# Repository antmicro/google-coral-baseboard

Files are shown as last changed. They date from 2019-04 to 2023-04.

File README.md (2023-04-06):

# Antmicro's Google Coral Baseboard

Copyright (c) 2019-2023 [Antmicro](https://www.antmicro.com)



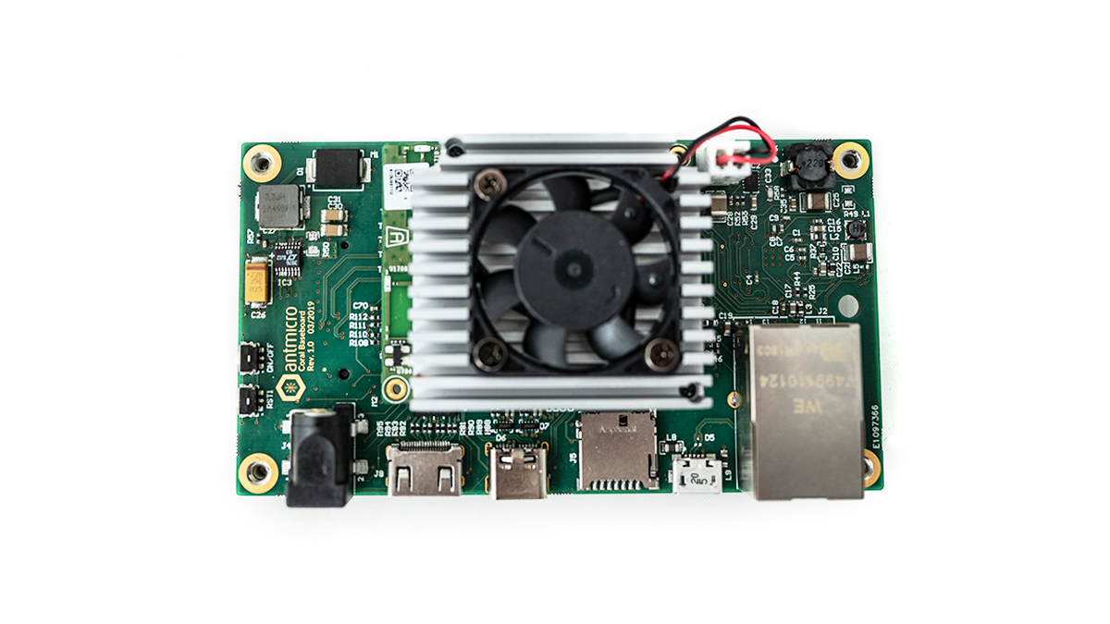
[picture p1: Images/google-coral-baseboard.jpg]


## Overview

This project contains open hardware design files for a baseboard supporting the [Google Coral SoM](https://coral.withgoogle.com/products/som) with NXP i.MX8X and Google's Edge TPU ML inference ASIC (also available as part of the [Coral Edge TPU Development Board](https://coral.withgoogle.com/products/dev-board), created by [Antmicro](https://www.antmicro.com).
The board provides standard I/O interfaces and allows the user to interface with two MIPI CSI-2 compatible video devices over a unified Flexible Flat Cable (FFC) connector.

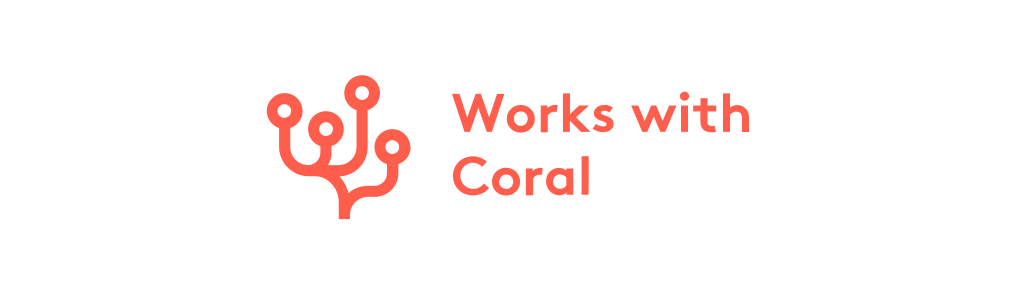
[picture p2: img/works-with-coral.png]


## Key features

* Interface connectors for the Coral Edge TPU module
* Gigabit Ethernet RJ45 connector
* Micro USB serial debug connector
* Micro SD card interface
* 50-pin FFC connectors exposing MIPI CSI-2 camera interfaces
* USB-C DFP (Host) port
* Mini HDMI video output interface
* Integrated DC/DC power supply accepting 6-36VDC of input voltage

The PCB project files were prepared in Altium Designer 14.1.

## Project structure

The main directory contains Altium project file, documentation script a
LICENSE and README. The remaining files are stored in the following
directories:

*   `Libraries` - contains the component libraries
*   `img` - contains graphics for this README
*   `PCB` - contains schematics and layout files 
*   `Documentation` - contains PDF schematic and generated assembly assets

## Getting started

The board can be produced and assembled using the provided design files.
Please take a look at the mechanical layers for more information regarding the PCB stackup recommended for fabrication.
The board accepts power supply voltage in the 6-36VDC range.
It is recommended to use a 12V 2A DC supply to power the board.
The board has an integrated power sequencer that starts the module automatically right after applying the power supply.
Please refer to the Coral documentation for more details regarding the [flashing procedure](https://coral.withgoogle.com/tutorials/devboard-reflash).

### Debug UART connection

Most of the debug messages are provided through the serial console.
The board is equipped with an FTDI chip exposing both UART interfaces to the host PC.
Please refer to the schematic sheets for more details.
The default debug UART channel is accessible through `/dev/ttyUSB0` (assuming that there are no other FTDI units connected to your PC).
The default baudrate for the serial debug connection is 115200 baud with 8-bit transmission, 1 stop bit and with no flow control.

## License

This project is licensed under the [Apache-2.0](LICENSE) license.

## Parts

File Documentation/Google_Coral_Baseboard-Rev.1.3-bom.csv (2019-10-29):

Designator | PartNumber | Value | Description | Manufacturer | MPN | Quantity
C1, C4, C5, C6, C7, C11, C16, C18, C20, C22, C23, C39, C50, C52, C55, C56, C57, C58, C59, C60, C61, C62, C63, C64, C80, C81 | C_100n_0402 | 100n | MLCC SMT Capacitor 100nF 0402 | Walsin | 0402X104K6R3CT | 26
C2, C3, C38, C45, C84, C85, C86 | C_100n_0402 | 100n | MLCC SMT Capacitor 100nF 0402 | Walsin | 0402X104K6R3CT | 7
C8, C9 | C_27p_0402 | 27p | MLCC SMT Capacitor 27pF 0402 | WALSIN | 0402N270J500CT | 2
C10, C25 | C_22u_1210 | 22u | MLCC SMT Capacitor 22uF 1210 | TDK | C3225X5R1A226M230AA | 2
C12 | C_10n_0603 | 10n | MLCC SMT Capacitor 10nF 0603 | AVX | 06031C103JAT2A | 1
C13 | C_100p_0603 | 100p | MLCC SMT Capacitor 100pF 0603 | WALSIN | 0603N101J500CT | 1
C14 | C_10p_0402 | 10p | MLCC SMT Capacitor 10pF 0402 | MULTICOMP | MC0402N100D500CT | 1
C15, C17, C19, C21 | C_4u7_0603 | 4u7 | MLCC SMT Capacitor 4u7F 0603 | TDK | C1608X5R1C475K080AC | 4
C24 | C_2u2_1210 | 2u2 | MLCC SMT Capacitor 2u2F 1210 | TDK | C3225X7R2A225K230AB | 1
C26 | C_100n_0603 | 100n | MLCC SMT Capacitor 100nF 0603 | AVX |  | 1
C27 | C_10n_0402 | 10n | MLCC SMT Capacitor 10nF 0402 | AVX |  | 1
C28 | C_1u_0402 | 1u | MLCC SMT Capacitor 1uF 0402 | Yaego | CC0402KRX5R5BB105 | 1
C29 | C_3n3_0603 | 3n3 | MLCC SMT Capacitor 3n3F 0603 | WALSIN | 0603B332J500CT | 1
C30, C31, C32 | C_2u2_1206 | 2u2 | MLCC SMT Capacitor 2u2F 1206 | Kemet |  | 3
C33 | C_470p_0603 | 470p | MLCC SMT Capacitor 470pF 0603 | AVX | 06031C471JAT2A | 1
C34 | C_4n7_0402 | 4n7 | MLCC SMT Capacitor 4n7F 0402 | TDK |  | 1
C35 | C_2n2_0603 | 2n2 | MLCC SMT Capacitor 2n2F 0603 | AVX | 06035C222KAT2A | 1
C36 | C_47p_0402 | 47p | MLCC SMT Capacitor 47pF 0402 | KEMET |  | 1
C37, C41 | C_1u_0603 | 1u | MLCC SMT Capacitor 1uF 0603 | Walsin | 0603F105Z160CT | 2
C40 | C_100u_1210_X5R | 100u | MLCC SMT Capacitor 100uF 1210 X5R | SAMSUNG | CL32A107MQVNNNE | 1
C42 | C_10u_0603 | 10u | MLCC SMT Capacitor 10uF 0603 | AVX | 06036D106MAT2A | 1
C43 | C_100n_0603 | 100n | MLCC SMT Capacitor 100nF 0603 | AVX |  | 1
C44 | C_47u_0805 | 47u | MLCC SMT Capacitor 47uF 0805 | KEMET |  | 1
C65, C66 | C_4u7_0402 | 4u7 | MLCC SMT Capacitor 4u7F 0402 | MURATA | GRM155R60G475ME | 2
C67, C68 | C_1u_0402 | 1u | MLCC SMT Capacitor 1uF 0402 | Yaego | CC0402KRX5R5BB105 | 2
C75, C76, C77 | C_47u_0805 | 47u | MLCC SMT Capacitor 47uF 0805 | KEMET |  | 3
C78, C79 | C_27p_0402 | 27p | MLCC SMT Capacitor 27pF 0402 | WALSIN | 0402N270J500CT | 2
C82, C83 | C_2p_0402 | 2p | MLCC SMT Capacitor 2p 0402 | TDK | C1005C0G1H020B050BA | 2
D1 | PDS760-13 | PDS760-13 | Schottky Diodes & Rectifiers SCHOTTKY RECTIFIER | DIODES INC. | PDS760-13 | 1
D2, D8, D9 | TPD2E009DRTR | TPD2E009DRTR | ESD Suppressors 2-CH | Texas Instruments | TPD2E009DRTR | 3
D4 | TPD6E05U06_PASS | TPD6E05U06 | ESD Suppressors 6-CH Pass through layout | Texas Instruments | TPD6E05U06RVZR | 1
D5 | TPD2E009DRTR | TPD2E009DRTR | ESD Suppressors 2-CH | Texas Instruments | TPD2E009DRTR | 1
D6, D7 | TPD4E05U06_PASS | TPD4E05U06 | ESD Suppressors 4-CH | Texas Instruments | TPD4E05U06DQAR | 2
D10 | 1N4148WS | 1N4148WS | Diode small signal | ON SEMICONDUCTOR | 1N4148WS | 1
F1 | LITTELFUSE_1206L450SLWR | 1206L450SLWR | PTC RESET 6V LO RHO 1206 4.50A | LITTELFUSE | 1206L450SLWR | 1
FAN1 | 022232021 A-6373-02A222 | MX-22-23-2021 | Pinhead connector with key | Molex |  | 1
FAN2 | B2B-PH-K-S(LF)(SN) | B2B-PH-K-S(LF)(SN) |  | JST |  | 1
IC1 | RTL8211F | RTL8211F | Highly Integrated 10/100/1000m Ethernet Transceiver | Realtek |  | 1
IC2 | MAX17502GATB+ | MAX17502GATB+ | DC-DC Switching (Step Down) Regulator, Adjustable, 600 kHz, 4.5V-60Vin, 0.9V-55.2V/1 A out, TDFN-10 | MAXIM INTEGRATED PRODUCTS | MAX17502GATB+ | 1
IC3 | TPS54561-Q1 | TPS54561-Q1 | IC REG BCK SPLIT RAIL ADJ 10WSON | TEXAS INSTRUMENTS | TPS54561-Q1 | 1
IC4 | FT2232D | FT2232D | Dual USB-UART/FIFO | FTDI | FT2232D-REEL | 1
IC5 | NCP380HSNAJAAT1G | NCP380HSNAJAAT1G | POWER LOAD SWITCH, HIGH SIDE | ON Semiconductor |  | 1
IC6 | HD3SS3220 | HD3SS3220 | IC DRP PORT CTLR USB-C 30WQFN | Texas Instruments |  | 1
IC7 | TPD8S009 | TPD8S009 | 8-Channel ESD Protection for DisplayPort and HDMI | TEXAS INSTRUMENTS |  | 1
IC8 | TLV70018DCKT | TLV70018DCKT | Voltage Regulator, 2V to 5.5V, 175mV Dropout, 1.8Vout, 200mAout | TEXAS INSTRUMENTS | TLV70018DCKT | 1
IC9 | PTN5150 | PTN5150 | CC logic for USB Type-C applications | NXP |  | 1
J1 | WE-687-150-145-22 | 68715014522 | 0.50mm SMT ZIF Horizontal Bottom Contact WR-FPC | WURTH ELEKTRONIK | 68715014522 | 1
J2 | WE_7499110124 | WE_7499110124 | LAN-Transformer WE-RJ45LAN 10/100/1000 BaseT | Wurth Elektronik | WE_7499110124 | 1
J4 | WE-694106106102 | 694106106102 | DC Power Jack Right Angled SMT Ø6.4 with 4 soldering pads & pegs WR-DC | WURTH ELEKTRONIK | 694106106102 | 1
J5 | AMP-114-00841-68 | 114-00841-68 | Micro SD card holder | AMPHENOL COMMERCIAL PRODUCTS | 114-00841-68 | 1
J6 | CON-Molex-47346-0001 | Molex 47346-0001 | USB - micro B Receptacle Connector 5 Position Surface Mount, Right Angle, Horizontal | Molex | 473460001 | 1
J7 | CON-Molex-105450-0101 | 105450-0101 | USB-C connector | Molex |  | 1
J8 | WE_685119136923 | 685119136923 | CONN HDMI FEMALE R/A 19POS 2.6MM | WURTH ELEKTRONIK |  | 1
J9 | CON-Molex-47346-0001 | Molex 47346-0001 | USB - micro B Receptacle Connector 5 Position Surface Mount, Right Angle, Horizontal | Molex | 473460001 | 1
JM0, JM1, JM3 | DF40HC(3.0)-100DS-0.4V(51) | DF40HC(3.0)-100DS-0.4V(51) | CONN RCPT 100POS 0.4MM SMD GOLD | Hirose |  | 3
L1 | ELLVGG4R7N | ELLVGG4R7N | PANASONIC ELECTRONIC COMPONENTS ELLVGG4R7N Surface Mount Power Inductor, Choke Coil, ELL-VGG Series, 4.7 ?H, ? 30%, Shielded, 0.17 ohm, 980 mA | PANASONIC ELECTRONIC COMPONENTS ELLVGG4R7N PANASONIC ELECTRONIC COMPONENTS | ELLVGG4R7N | 1
L2, L3, L4, L5 | BLM18PG330SN1D | BLM18PG330SN1D | MURATA BLM18PG330SN1D FERRITE BEAD, 0.025OHM, 3A, 0603 | MURATA | BLM18PG330SN1D | 4
L6 | 744777122 | 744777122 | Surface Mount Power Inductor, WE-PD Series, 22 µH, 1.41 A, 1.7 A, Shielded, 0.11 ohm | WURTH ELEKTRONIK | 744777122 | 1
L7 | WE_7447798720 | WE_7447798720 | Fixed Inductors WE-PDF 1064 7.2uH 7.9A 12.8mOhm | WURTH ELEKTRONIK |  | 1
L8 | 742792022 | 742792022 | WURTH ELEKTRONIK - 742792022 - FERRITE BEAD, 0.05OHM, 2A, 0805 | WURTH ELEKTRONIK | 742792022 | 1
L9 | BLM18SG121TN1D | BLM18SG121TN1D | FERRITE BEAD, 0.025OHM, 3A, 0603 | MURATA | BLM18SG121TN1D | 1
L10 | BLM18EG221SN1D | BLM18EG221SN1D | MURATA BLM18EG221SN1D FERRITE BEAD, 0.05OHM, 2A, 0603 | MURATA | BLM18EG221SN1D | 1
L11 | 742792022 | 742792022 | WURTH ELEKTRONIK - 742792022 - FERRITE BEAD, 0.05OHM, 2A, 0805 | WURTH ELEKTRONIK | 742792022 | 1
L12 | BLM18SG121TN1D | BLM18SG121TN1D | FERRITE BEAD, 0.025OHM, 3A, 0603 | MURATA | BLM18SG121TN1D | 1
L13 | BLM18AG601SN1D | BLM18AG601SN1D | Ferrite Bead, 600 ohm, 0603 [1608 Metric], BLM18A Series, 500 mA, 0.38 ohm, ? 25% | MURATA | BLM18AG601SN1D | 1
LED1 | LED_R | KPT-1608EC | LED Red 0603 case | KINGBRIGHT | KPT-1608EC | 1
M2 | Edge-TPU-SOM-model |  | Edge TPU SOM |  |  | 1
ON/OFF, RST1 | TL3340AF160QG | TL3340AF160QG | E-SWITCH TL3340AF160QG SWITCH, TACTILE SPST 50mA, SMD GULL WING | E-SWITCH |  | 2
Q1 | NX5427001Z | NX5427001Z | CLOCK SAW OSCILLATOR SEAM5032 | Diodes Incorporated |  | 1
Q2 | PMV32UP | PMV32UP | P CH, 20V, 4A | NXP | PMV32UP | 1
R1, R2, R3, R4 | R_2k_0402 | 2k | SMT Resistor 2k 0402 | VISHAY | CRCW04022K00FKED | 4
R6, R7, R8, R9, R10, R19, R20, R22, R23, R82, R86 | R_4k7_0402 | 4k7 | SMT Resistor 4k7 0402 | PANASONIC ELECTRONIC COMPONENTS | ERJ2GEJ472X | 11
R16, R60, R61, R62, R63, R64, R65, R66, R87, R101, R116, R121, R122, R123, R126 | R_10k_0402 | 10k | SMT Resistor 0402 | VISHAY | CRCW040210K0FKEDHP | 15
R26, R44, R98, R132, R133, R134, R135, R136, R137, R138 | R_0R_0402 | 0R | SMT Resistor 0402 |  |  | 10
R27, R28, R29, R30, R32, R33, R39, R41, R43, R47, R71, R76, R77, R83, R84, R96, R97, R120, R127, R128, R129, R130 | R_0R_0402 | 0R | SMT Resistor 0402 |  |  | 22
R31 | R_220R_0402 | 220R | SMT Resistor 220R 0402 | TE CONNECTIVITY / NEOHM | CRG0402J220R | 1
R34, R35, R36, R38, R40, R42 | R_22R_0402 | 22R | SMT Resistor 22R 0402 | VISHAY | CRCW040222R0FKED | 6
R37 | R_2k49_0603_1% | 2k49 | SMT Resistor 2k49 0603 1% | Vishay | CRCW06032K49FKEA | 1
R45 | R_2k_0402 | 2k | SMT Resistor 2k 0402 | VISHAY | CRCW04022K00FKED | 1
R46, R58 | R_10k_0402 | 10k | SMT Resistor 0402 | VISHAY | CRCW040210K0FKEDHP | 2
R48, R49, R67 | R_0R_0805 | 0R | SMT Resistor 0R 0805 | VISHAY | CRCW08050000Z0EA | 3
R50, R53, R79, R80 | R_2k2_0402 | 2k2 | RES, 2k2, 0402, 5% | MULTICOMP | MCWR04X2201FTL | 4
R51 | R_3M3_0402 | 3M3 | SMT Resistor 3M3 0402 | WELWYN | ASC0402-3M3FT10 | 1
R52 | R_44k2_0402 | 44k2 | SMT Resistor 0402 | PANASONIC ELECTRONIC COMPONENTS | ERJ2RKF4422X | 1
R55 | R_16k5_0402_0.1% | 16k5 | RES, 16k5, 0402, 0.1% | PANASONIC ELECTRONIC COMPONENTS | ERA2AEB1652X | 1
R56 | R_0R_1206 | 0R | RES, 0R, 1206 |  |  | 1
R57 | R_243k_0402 | 243k | RES, 243k, 0402 |  |  | 1
R59 | R_49R9_0402 | 49R9 | RES, 49R9, 0402 |  |  | 1
R68 | R_470R_0402 | 470R | SMT Resistor 470R 0402 | VISHAY | CRCW0402470RFKED. | 1
R70 | R_470R_0603 | 470R | SMT Resistor 470R 0603 | BOURNS | CR0603-JW-471GLF | 1
R73 | R_5k6_0603 | 5k6 | SMT Resistor 5k6 0603 | PANASONIC ELECTRONIC COMPONENTS | ERJ3GEYJ562V | 1
R74, R78 | R_200k_0402 | 200k | SMT Resistor 200k 0402 | YAGEO (PHYCOMP) | RC0402FR-07200KL | 2
R75 | R_909k_0402 | 909k | SMT Resistor 9k31 0402 | PANASONIC ELECTRONIC COMPONENTS | ERJ2RKF9093X | 1
R88, R89, R90, R91, R92, R93, R94, R95 | R_5R6_0402 | 5R6 | SMD Resistor 0402 | Panasonic | ERJ2GEJ5R6X | 8
R99 | R_0R_0603 | 0R | SMT Resistor 0R 0603 | BOURNS | CR0603-J/-000ELF | 1
R100 | R_1k54_0402 | 1k54 | SMT Resistor 1k54 0402 | VISHAY | CRCW04021K54FKED. | 1
R102 | R_53k6_0402 | 53k6 | SMT Resistor 0402 | TE CONNECTIVITY |  | 1
R103, R104, R105, R106 | R_33R_0402 | 33R | RES, 33R, 0402, 1% | TE CONECTIVITY | CRG0402F33R | 4
R113 | R_16k9_0402 | 16k9 | SMT Resistor 0402 | PANASONIC |  | 1
R114 | R_10k2_0402_0.1% | 10k2 | RES, 10k2, 0402, 0.1% | TE CONECTIVITY | CPF0402B10K2E1 | 1
R115 | R_1M_0402 | 1M | SMT Resistor 1M 0402 | VISHAY | CRCW04021M00FKED | 1
R117, R131 | R_100k_0402 | 100k | SMT Resistor 100k 0402 | VISHAY | CRCW0402100KFKEDHP | 2
R118, R119 | R_1k8_0603 | 1k8 | SMT Resistor 1k8 0603 | VISHAY | CRCW06031K80FKEA | 2
R124, R125 | R_5k11_0402 | 5k11 | SMT Resistor 5k11 0402 | WALSIN | WR04X5111FTL | 2
SW1 |  | TDA02H0SB1 | TDA02H0SB1 - DIP / SIP Switch, 2 Circuits, SPST, SMD, TDA Series, DIP, 24 V | C & K |  | 1
Y1 | CRYSTAL_25MHz_SMD_TXC | 25MHz | CRYSTAL, 25.000MHZ | TXC | 7A-25.000MAAJ-T | 1
Y2 | CRYSTAL_6_MHz_SMD | MQ-6.000-12-30/30/ | CRYSTAL, 6MHZ, 12PF, SMD,30ppm | MERCURY UNITED ELECTRONICS | MQ-6.000-12-30/30/-40+85 | 1

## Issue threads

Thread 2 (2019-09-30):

This board will never power up the SOM

ajawamnet, 2019-09-30:
According to Schmoogle - you need to have pins 93 thru 100 on what you call JM3 (google SOM Dev board J1312) connected to 5 volt.

But your board shows those pins connected to VSYS_5V via polyfuse F1 - and VSYS_5V goes nowhere - see the altium screenshot attached...

AND you show pin 93 tied to GND - not cool

See the screenshot of the Google SOM datasheet - where it states that you MUST connect those pins.

What kind of man-bun, java-jockey crap is this?

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

pkatarzynski, 2019-10-01:
Hi
Thank you for your contribution.
We have updated power delivery for the SOM.

ajawamnet, 2019-10-01:
OK - I'll look for the updated github files

--
WAM
http://www.ajawamnet.com
http://www.ajawamnet.com/ajawamnet/marketturd.htm
------------

More information on my lab and shop:
http://www.ajawamnet.com
http://www.ajawamnet.com/ajawam3/swarf/swarf.htm
------------------------
"Success is going from failure to failure without a loss of enthusiasm."
~~ Sir Winston Leonard Spencer-Churchill (1874-1965)

"I've failed at so many things so many times I make Abraham Lincoln look like Bill Gates"
~~ Wayne Mitzen (1959-  )

"What makes an expert isn't so much what they know,
It's that they've done similar things so many times wrong
They know what not to do"
~~ Wayne Mitzen (1959-  )

"You just keep pushing. You just keep pushing. I made every mistake that could be made. But I just kept pushing."
~~ Rene Descartes 1596-1650

"I hate the way people just go from ignorance to despair so quickly; it's the lazy man's option"
~~Professor Tim Flannery (1956-  )

"When you do things right, people won't be sure you've done anything at all."
~~ God, in Futurama episode "Godfellas"

"Two things are infinite: the universe and human stupidity;
and I'm not even sure about the universe."
~~ Albert Einstein (1879-1955)

"Some scientists claim that hydrogen, because it is so plentiful, is the basic building block of the universe.
I dispute that. I say there is more stupidity than hydrogen, and that is the basic building block of the universe."
~~ Frank Zappa (1940-1993)

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

Closed 2019-10-01.

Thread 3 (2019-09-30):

You also have a problem with parts flipped on layer in the PCB

ajawamnet, 2019-09-30:
Oh and in the Altium PCB file you have multiple parts that are shown as flipped on layer. In Altium 19 you'd never notice this (since they went f'ing brain dead and removed a lot of stuff we've come to depend on) BUT it is an issue if you're using AD17 or lower... this is bad mojo - ask any seasoned Altium user (me - I've done over 3,500 design with their tool since 1995).

Ya might want to fix this...

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

pkatarzynski, 2019-10-01:
Hi

Thank you for your comment.
The design files were prepared in Altium Designer 14.1
We can see that some of the components on bottom layer have the 'flipped on layer' attribute set in the design however the pin arrangement on those footprints matches the physical arrangement on ICs. We will review the component library and unify this.

ajawamnet, 2019-10-02:
The easiest thing to do is to open in AD19 and save out. This will clear the flipped on layer. You can then  use the Make PCBLib.
- Attached is the PCB with the power issue fix (your upload of 191001)   saved out of AD19.1.7 and re-saved as AD14.2 - along with the PCBLib saved out of AD14.2 with the report generated in AD17 (since PCBList in AD14 did not have a column for Flipped on Layer attribute) that shows all the "Flipped on layer" stoopid has been reset.

[PCB-withpwrfix-ad19_to_ad14.zip](https://github.com/antmicro/google-coral-baseboard/files/3681559/PCB-withpwrfix-ad19_to_ad14.zip)

Also note I moved the "Cool ass" open source logo to clear the DRC from the keepout.

BTW - the guy that runs the Free Software Foundation - the GNU thing - Richard Stallman. He HATES the term "Open Source". If you mention  "Open Source" to him more than a few times he'll stop talking/email chatting with you.

The silly I've seen since I started back in the late 1970's ... all the cool man-bun java jockey maker crap - see my rant here: http://www.ajawamnet.com/ajawamnet/mama_i_wanna_be_a_maker.html

Good lord...

ajawamnet, 2019-10-02:
updated PCB doc in AD14.2 format with adjustment for silly Open Source logo bottom soldermask

[PCB-withpwrfix-ad19_to_ad14.zip](https://github.com/antmicro/google-coral-baseboard/files/3682505/PCB-withpwrfix-ad19_to_ad14.zip)

pkatarzynski, 2019-10-04:
Thank you for your assistance. We have updated the PCB components with proper definitions of flipped-on-layer attribute.

Closed 2019-10-04.

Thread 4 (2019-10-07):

BAD MOLEX USB Footprint

ajawamnet, 2019-10-07:
See the attached JPG... also attached is corrected footprint
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

[correctedmlxUSB.zip](https://github.com/antmicro/google-coral-baseboard/files/3698487/correctedmlxUSB.zip)

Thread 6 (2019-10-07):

Lack of SOM Mounting holes as per Google Datasheet

ajawamnet, 2019-10-07:
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

https://coral.withgoogle.com/docs/dev-board/datasheet/

pkatarzynski, 2019-10-07:
Hi ajawamnet
We have dropped mounting holes on purpose in the first revision because of time constraints. Holes will be there in the next revision probably.

Closed 2019-10-07.

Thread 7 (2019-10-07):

Your baseboard has components and copper in the area that Google mentions should be clear of these elements

ajawamnet, 2019-10-07:
See the attached:
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

pkatarzynski, 2019-10-29:
We have added clearance area in revision 1.3

ajawamnet, 2019-10-29:
I hope that's enough - if you look at the Google ref baseboard, note there's nothing beyond the clearance area - the SOM is mounted at the edge of the PCB.  Even on your 1.3 rev, the WiFi will be radiating into your main power inductor ... not sure how that big honkin' piece of ferrite will affect the pattern and the loading/tuning of that PCB antenna they use. Be interesting to see how that works...

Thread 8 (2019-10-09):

SOM Fan connector is incorrect

ajawamnet, 2019-10-09:
The SOM actually uses a 2mm JST connector for the fan

pkatarzynski, 2019-10-09:
We have some heatsink assemblies with fans terminated with Molex KK-Series. The board was originally designed for such a fan. However it is a good idea to support both Molex and JST. We will add JST connector in next revision.

Closed 2019-10-09.

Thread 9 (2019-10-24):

PCIE CLKREQ goes nowhere

ajawamnet, 2019-10-24:
the label PCIE2_nCLKREQ (I2C4_SDA) on JM1 pin 78 does not match the PCIE1_nCLKREQ  label on  M.2 interface pin 52

pkatarzynski, 2019-10-25:
Hi

Thank you for spotting this.
According to the latest datasheet of the Som (https://coral.withgoogle.com/docs/som/datasheet/#pcie)
both PCIe interfaces are used internally.
This information was not available when we designed the very first version of the baseboard. Hence we are going to drop the M.2 at this point.

Closed 2019-10-25.

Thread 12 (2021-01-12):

SOM not working according to this datasheet.

borguleabhijeet, 2021-01-12:
Hello, I have made a pcb to mount SOM product. I am more interested in GPIO pins so I kept other peripherals floating.
The board just take input +5v and Ground. After all pcb fabrication and assembly the SOM module  only heats up and do not get booted. I changed the boot mode but its not working. Can you please help me to solve the issue?
The schematic is attached to below link. I already browned one SOM module. I afraid to connect another one.

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

Closed 2021-01-14.

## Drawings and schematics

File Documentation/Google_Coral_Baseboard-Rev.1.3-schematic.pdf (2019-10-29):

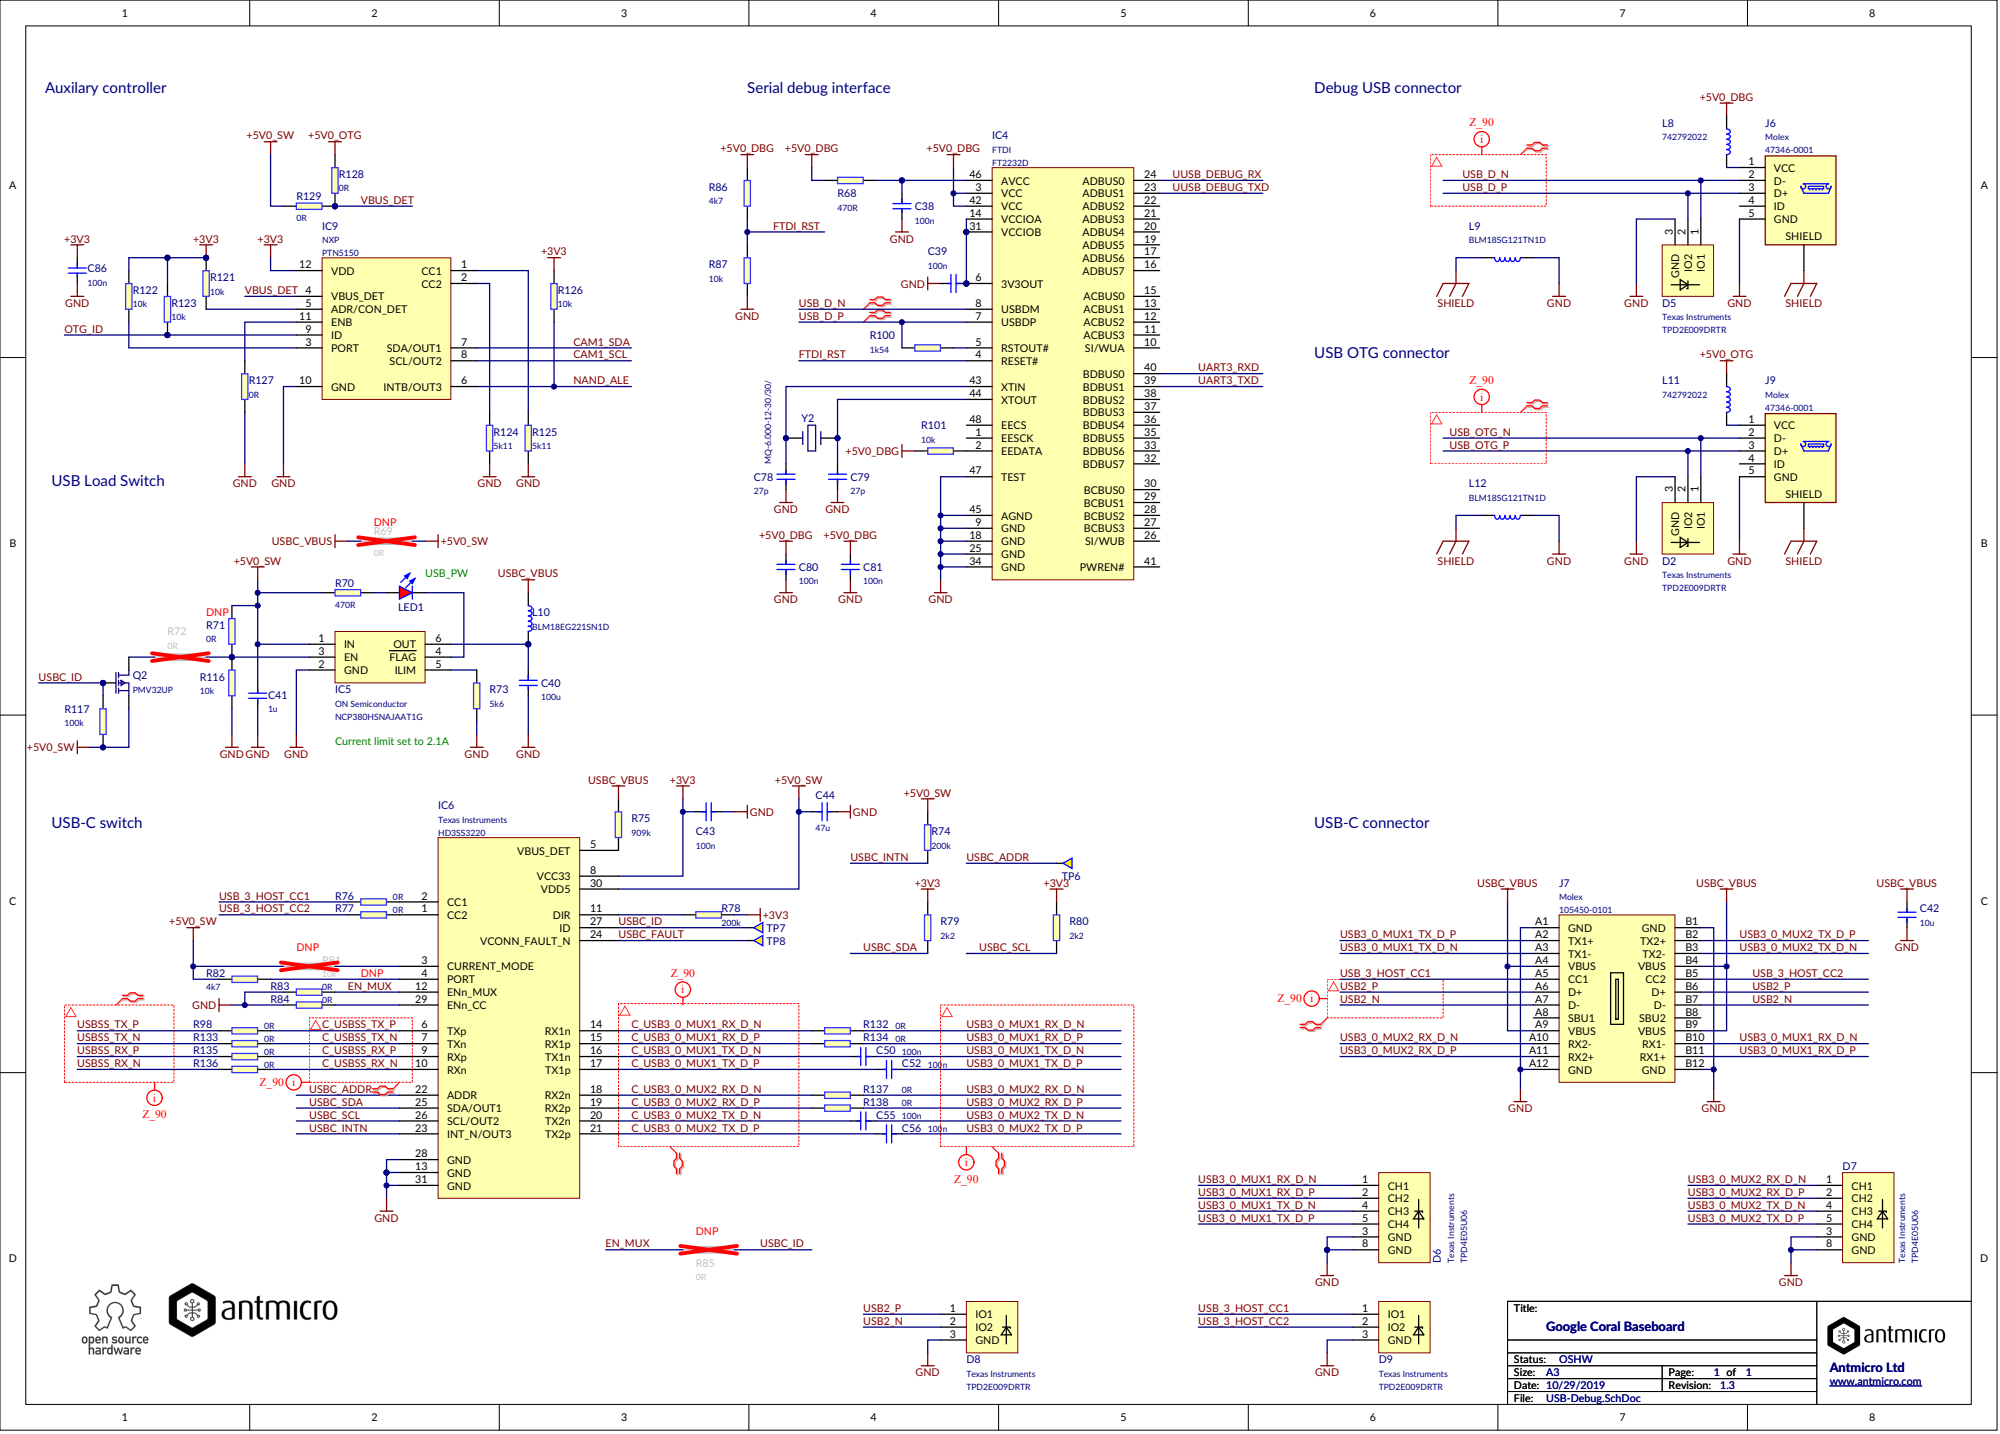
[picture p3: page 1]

PORT 3

XTOUT 44

AGND 45
GND 9
GND 18
GND 25

Current limit set to 2.1A

Size: A3 | Page: 1 of 1
Date: 10/29/2019 | Revision: 1.3

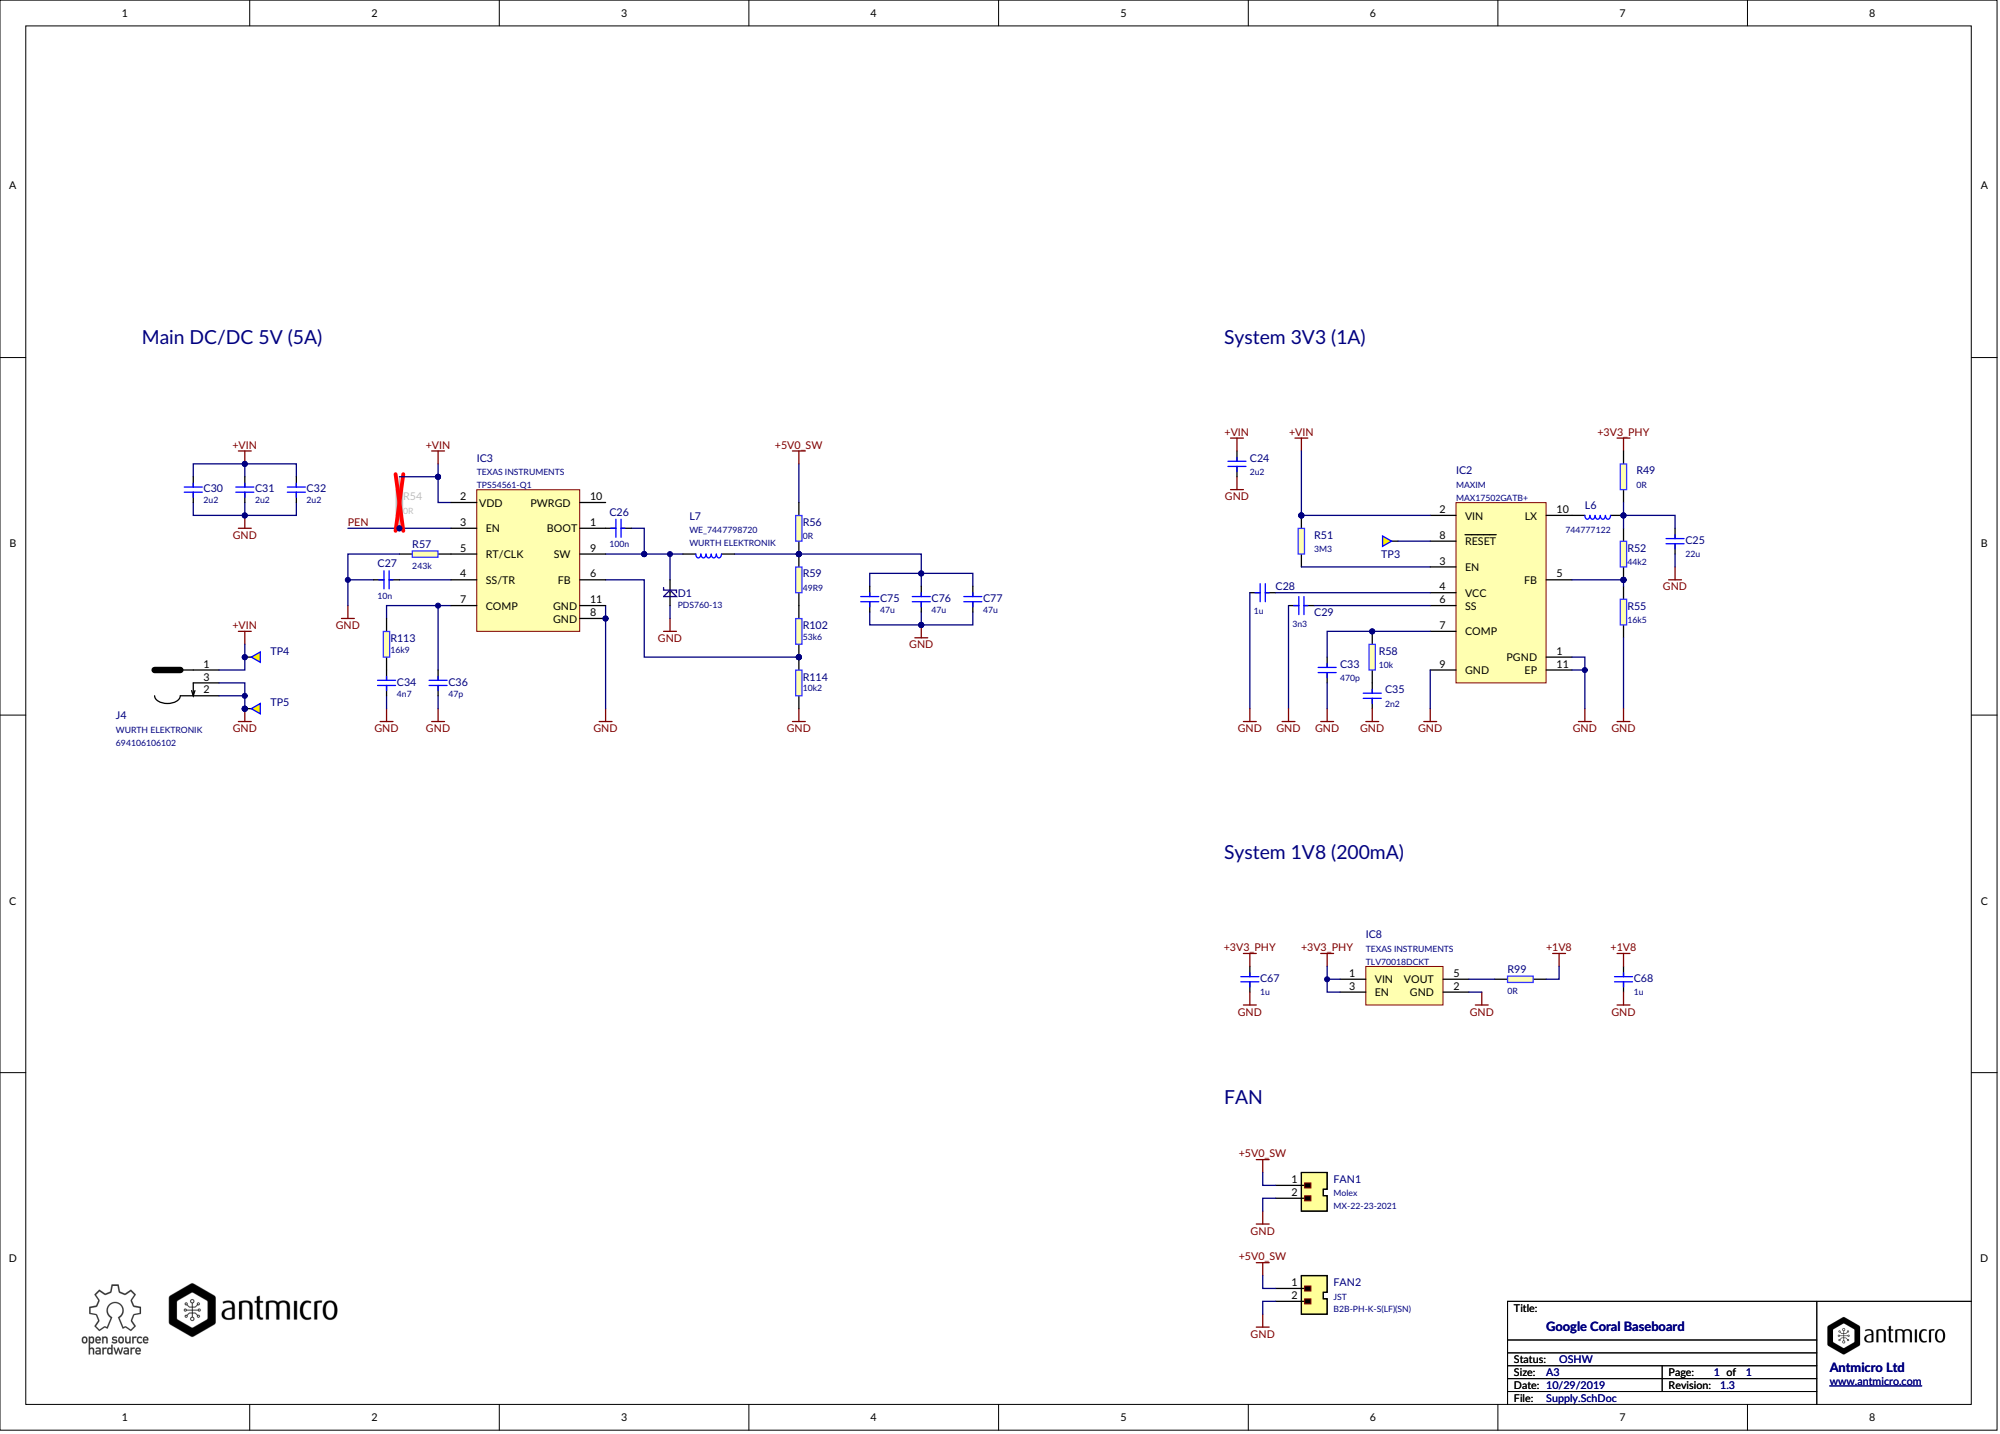
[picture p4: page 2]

COMP 7

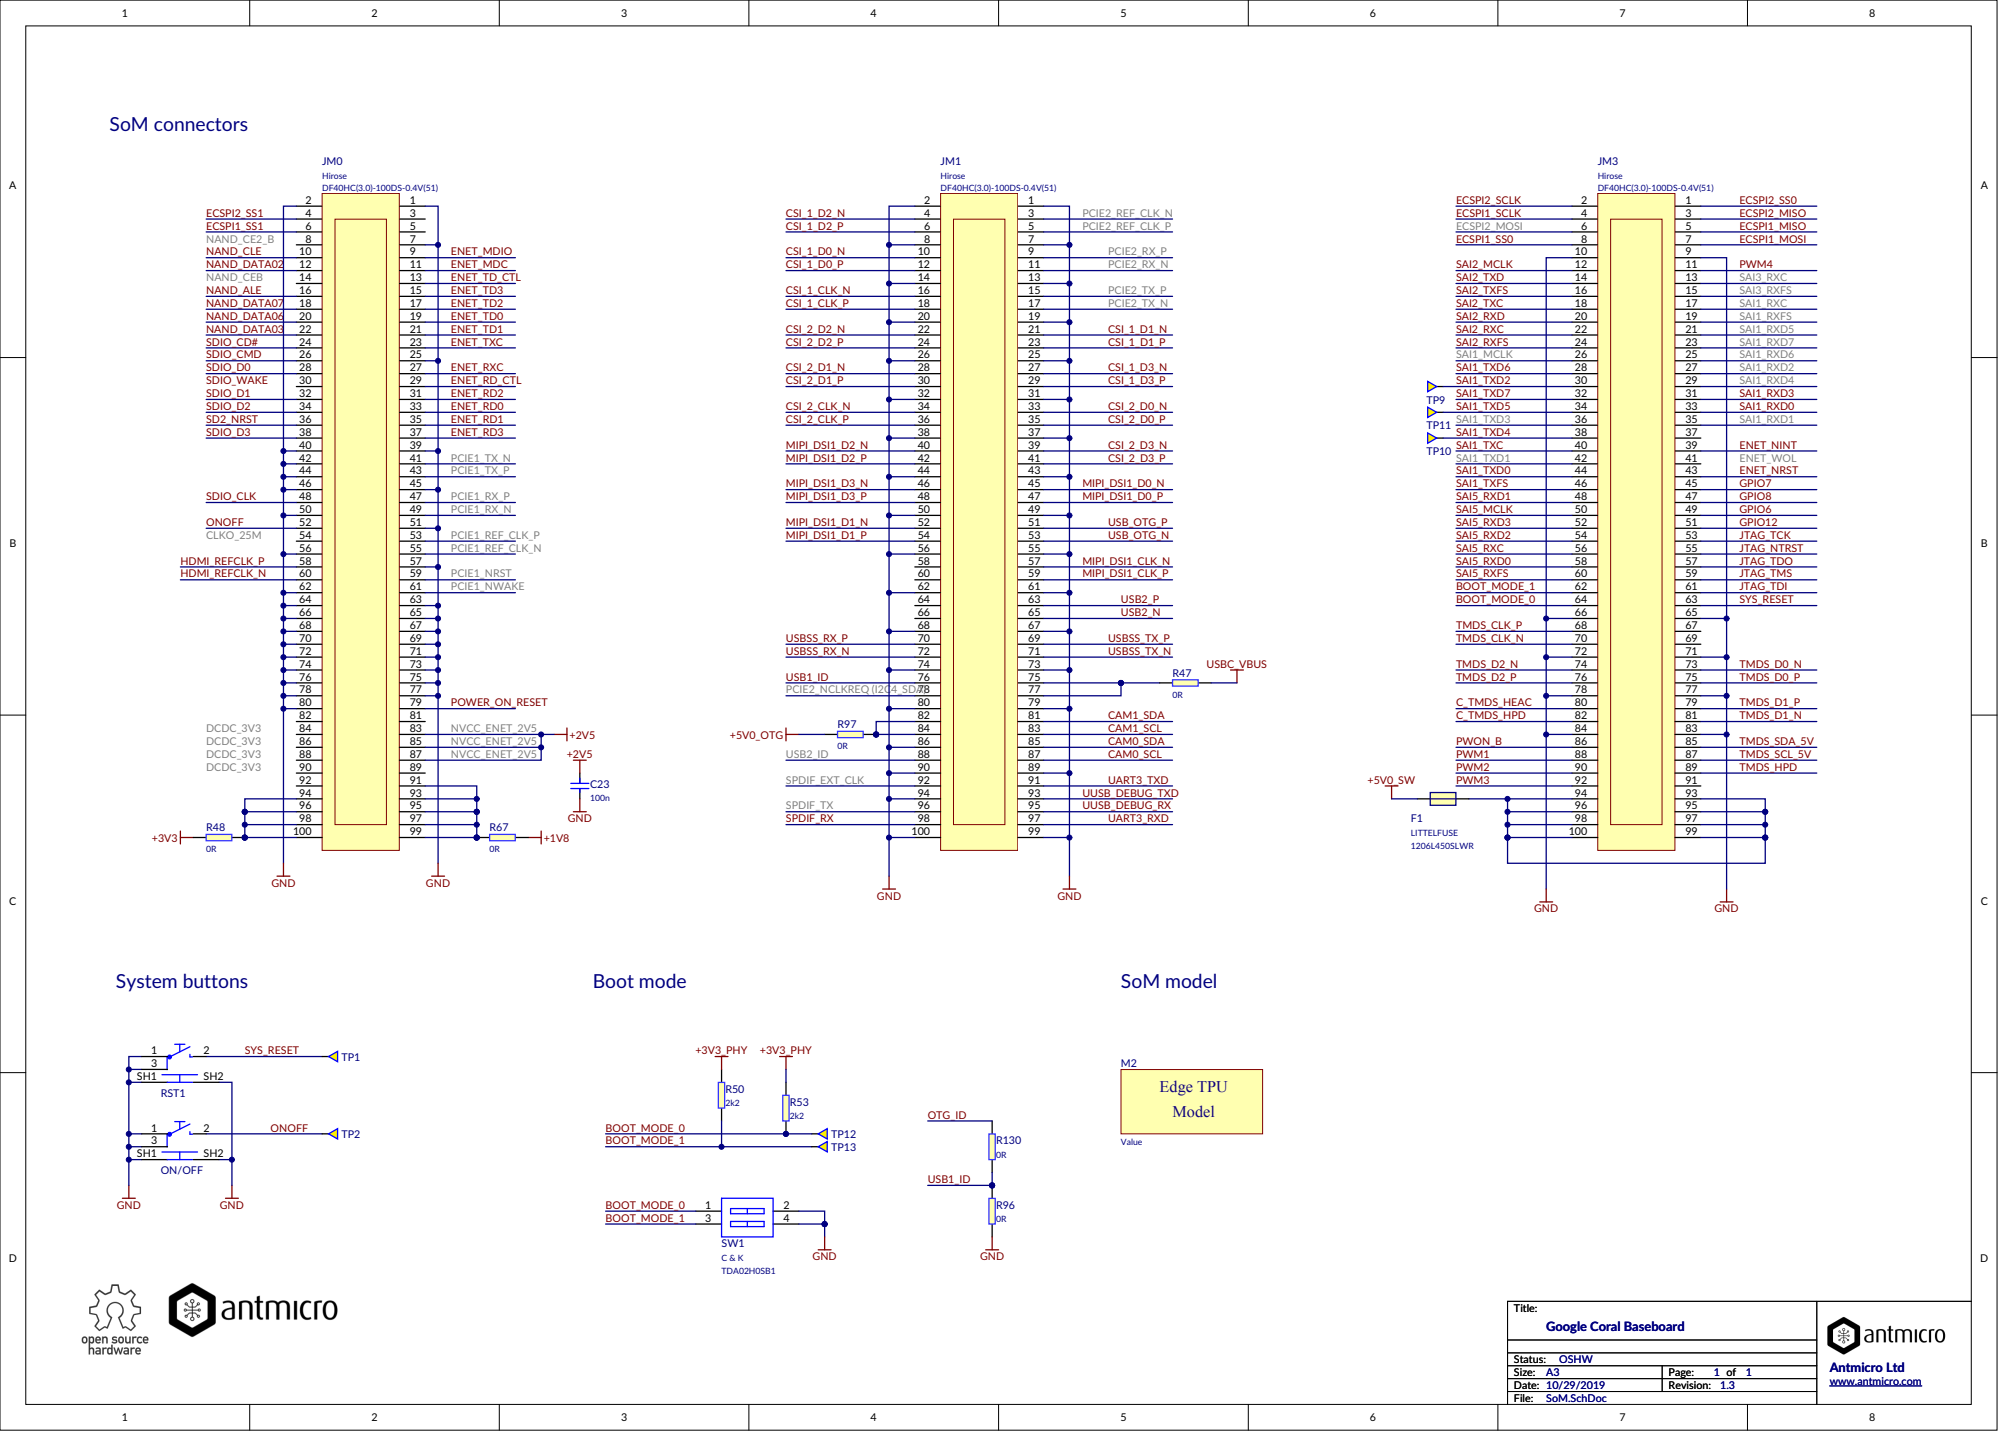
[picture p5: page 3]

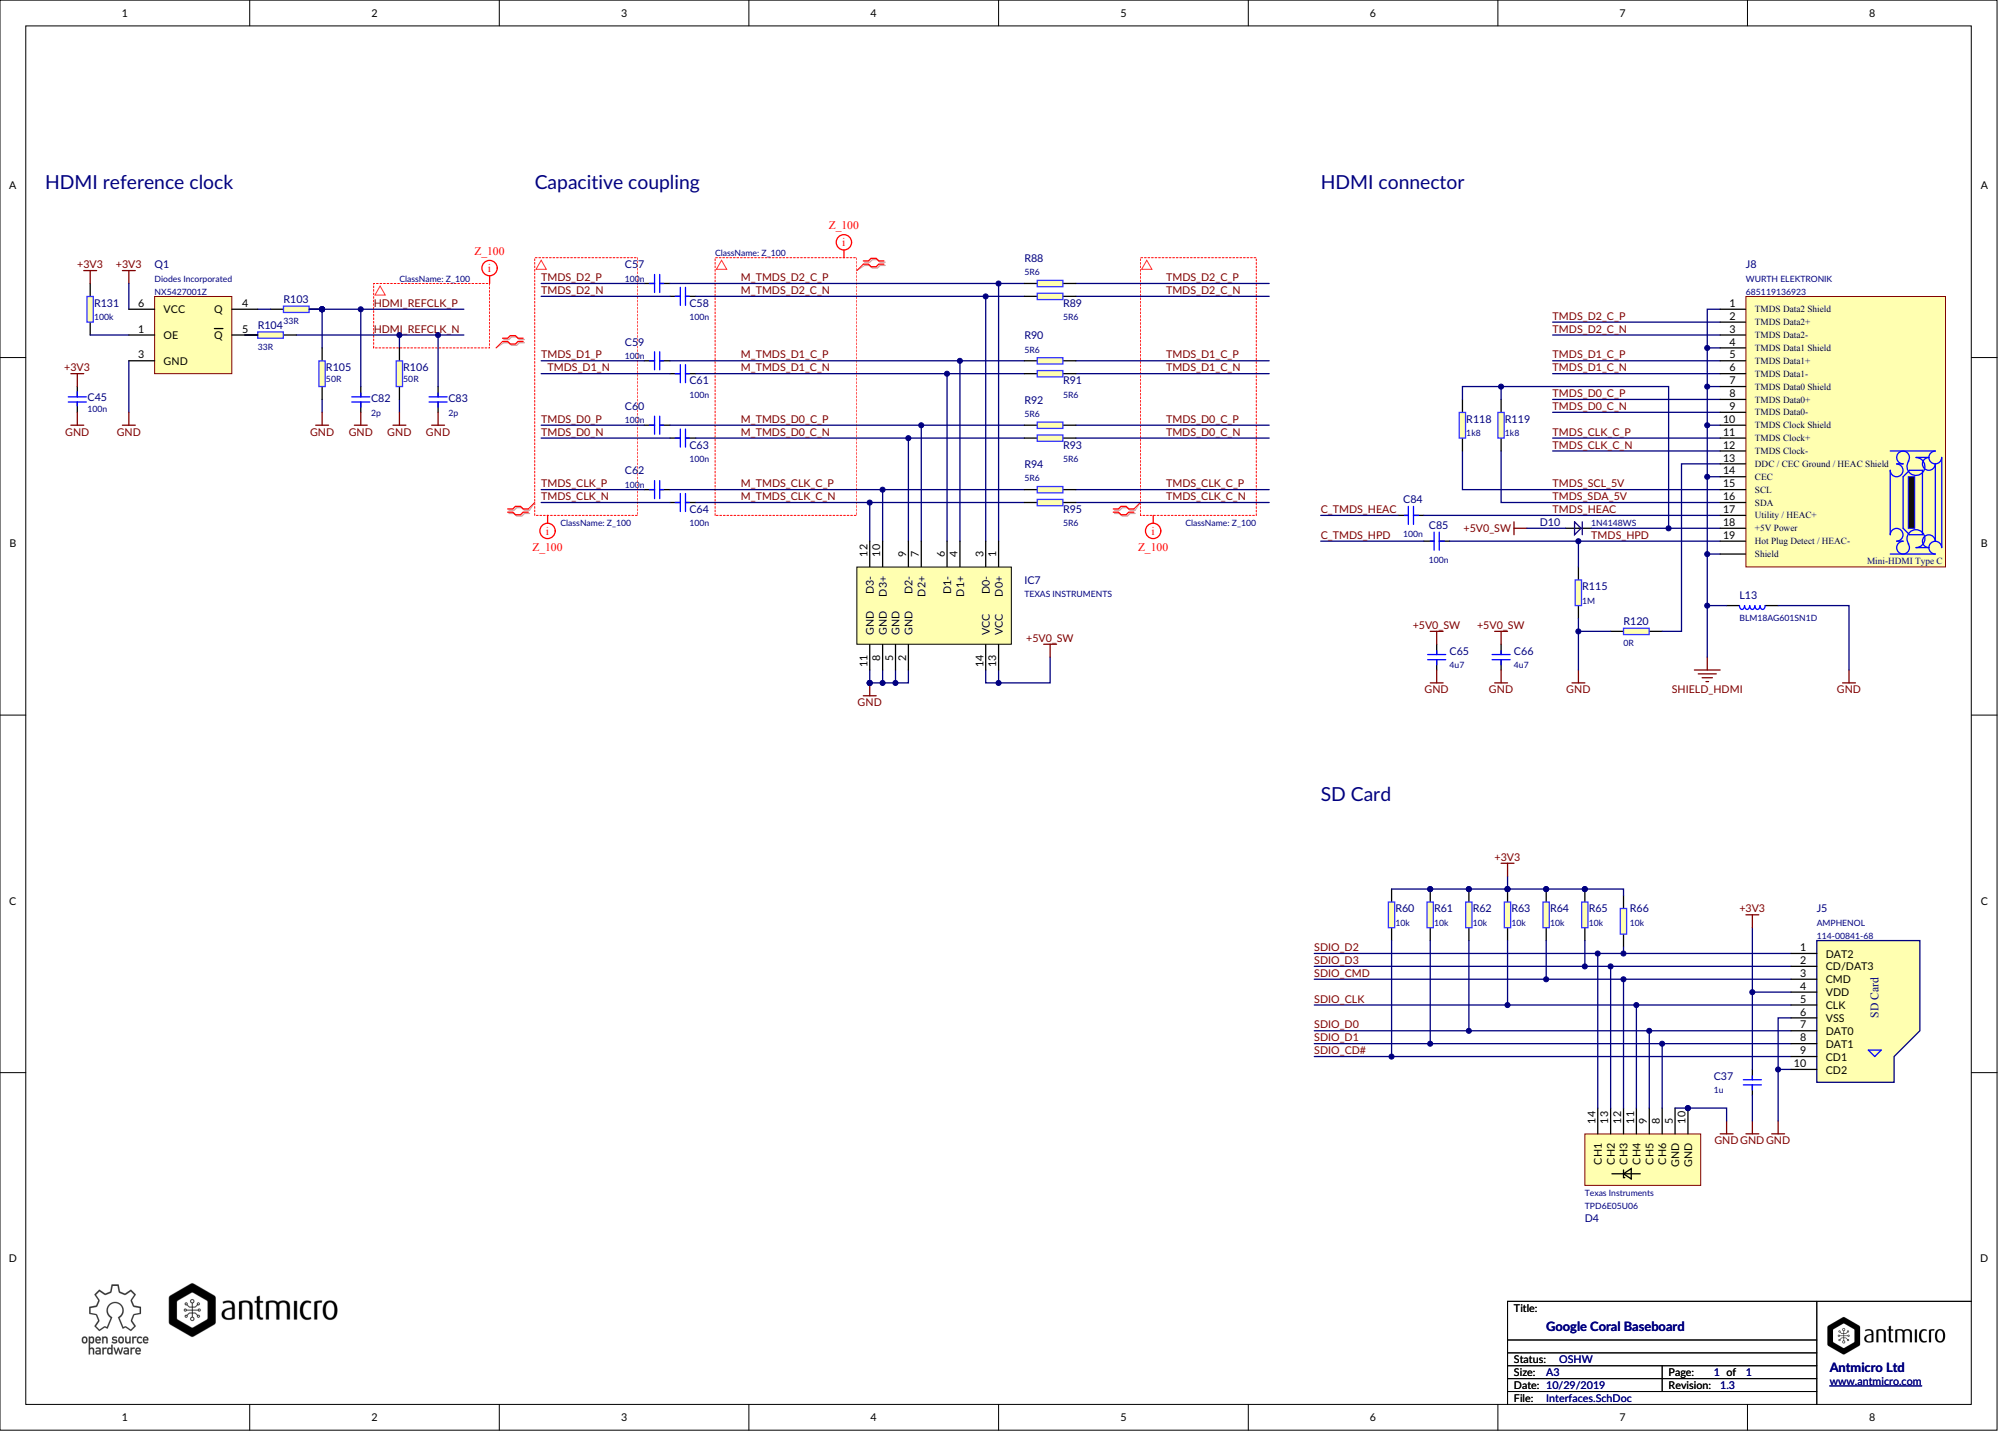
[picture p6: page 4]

TMDS Data1+ 5 TMDS Data1- 6 TMDS Data0 Shield 7

TMDS Data0+ 8 TMDS Data0- 9 TMDS Clock Shield 10

DDC / CEC Ground / HEAC Shield 13
CEC 14
SCL 15

+5V Power 18
Hot Plug Detect / HEAC- 19

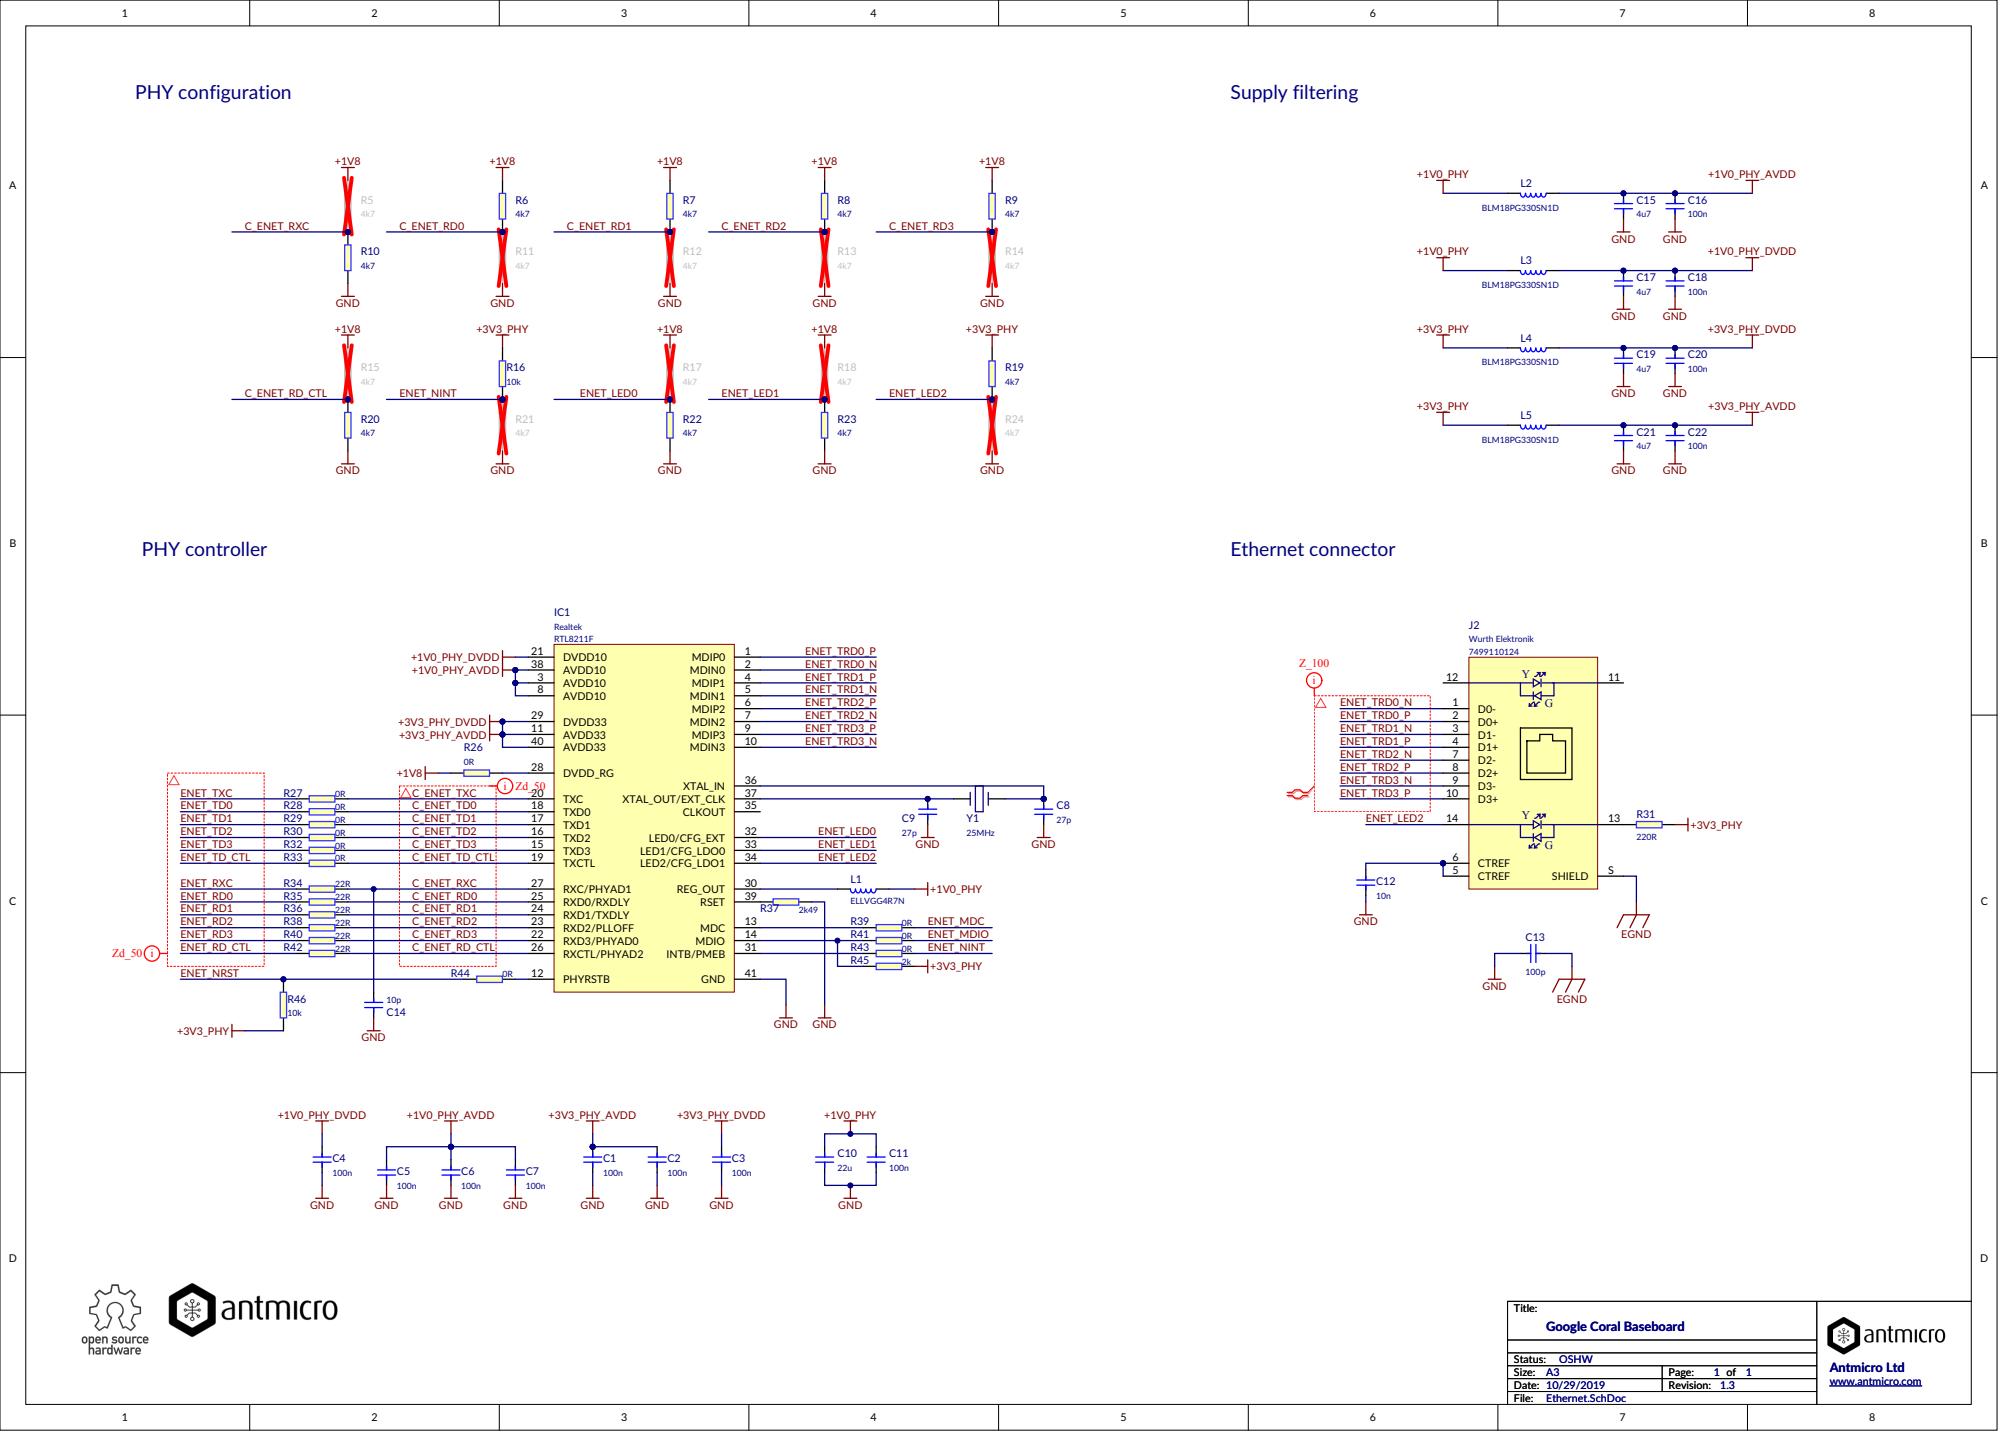
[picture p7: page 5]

C_ENET_TD0

C_ENET_TD1 | TXD3 15 TXD2 16 TXD1 17 TXD0 18

C_ENET_RXC | | RXC/PHYAD1 27
C_ENET_RD0

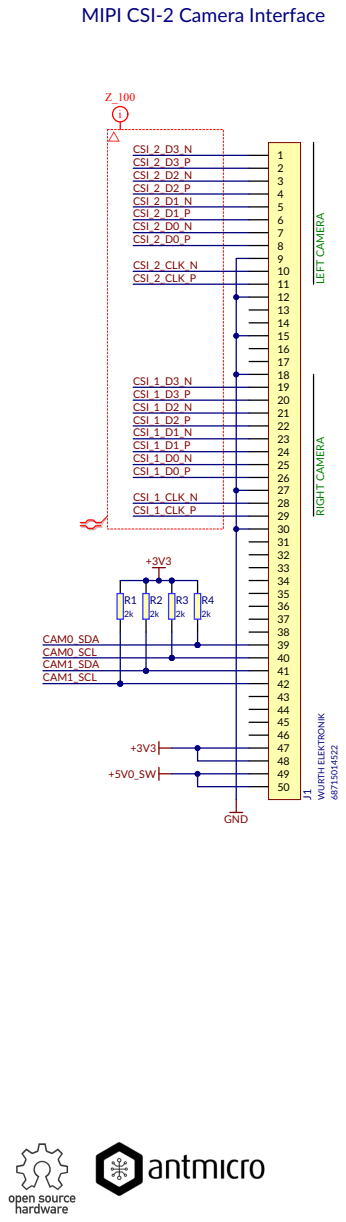
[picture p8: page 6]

MIPI CSI-2 Camera Interface

LEFT CAMERA RIGHT CAMERA

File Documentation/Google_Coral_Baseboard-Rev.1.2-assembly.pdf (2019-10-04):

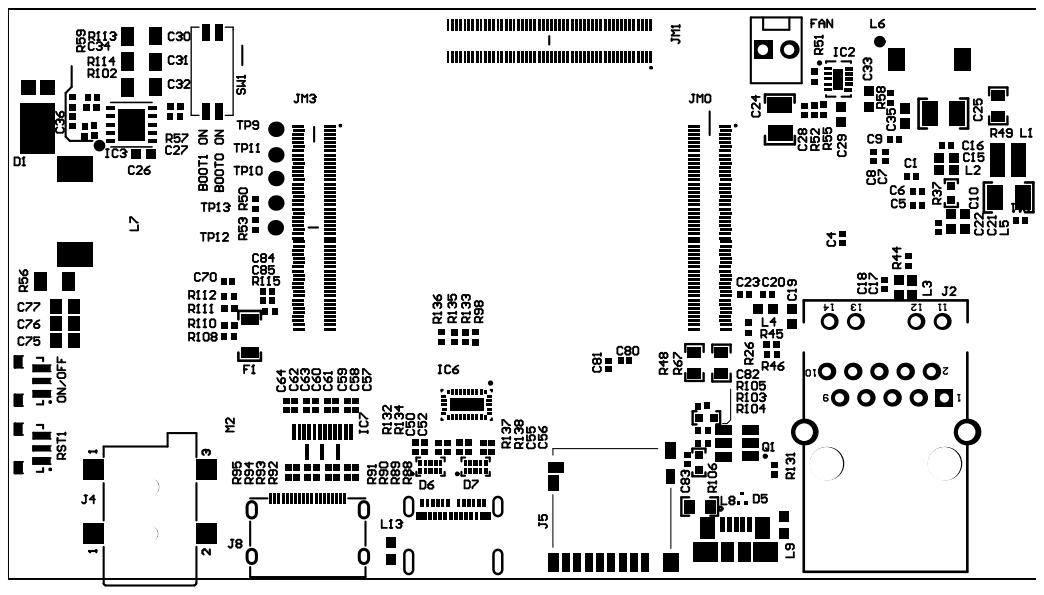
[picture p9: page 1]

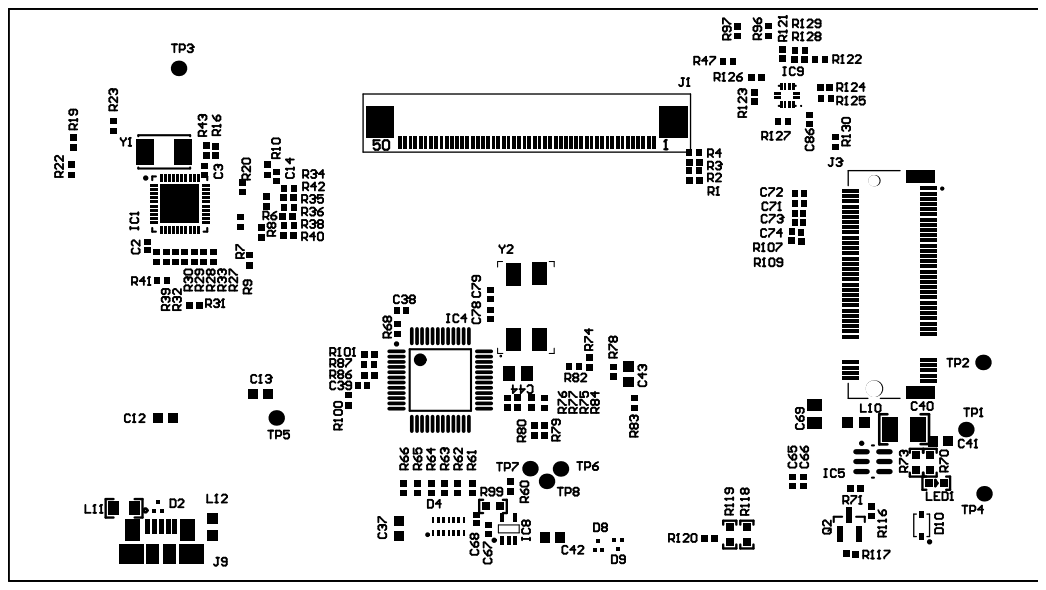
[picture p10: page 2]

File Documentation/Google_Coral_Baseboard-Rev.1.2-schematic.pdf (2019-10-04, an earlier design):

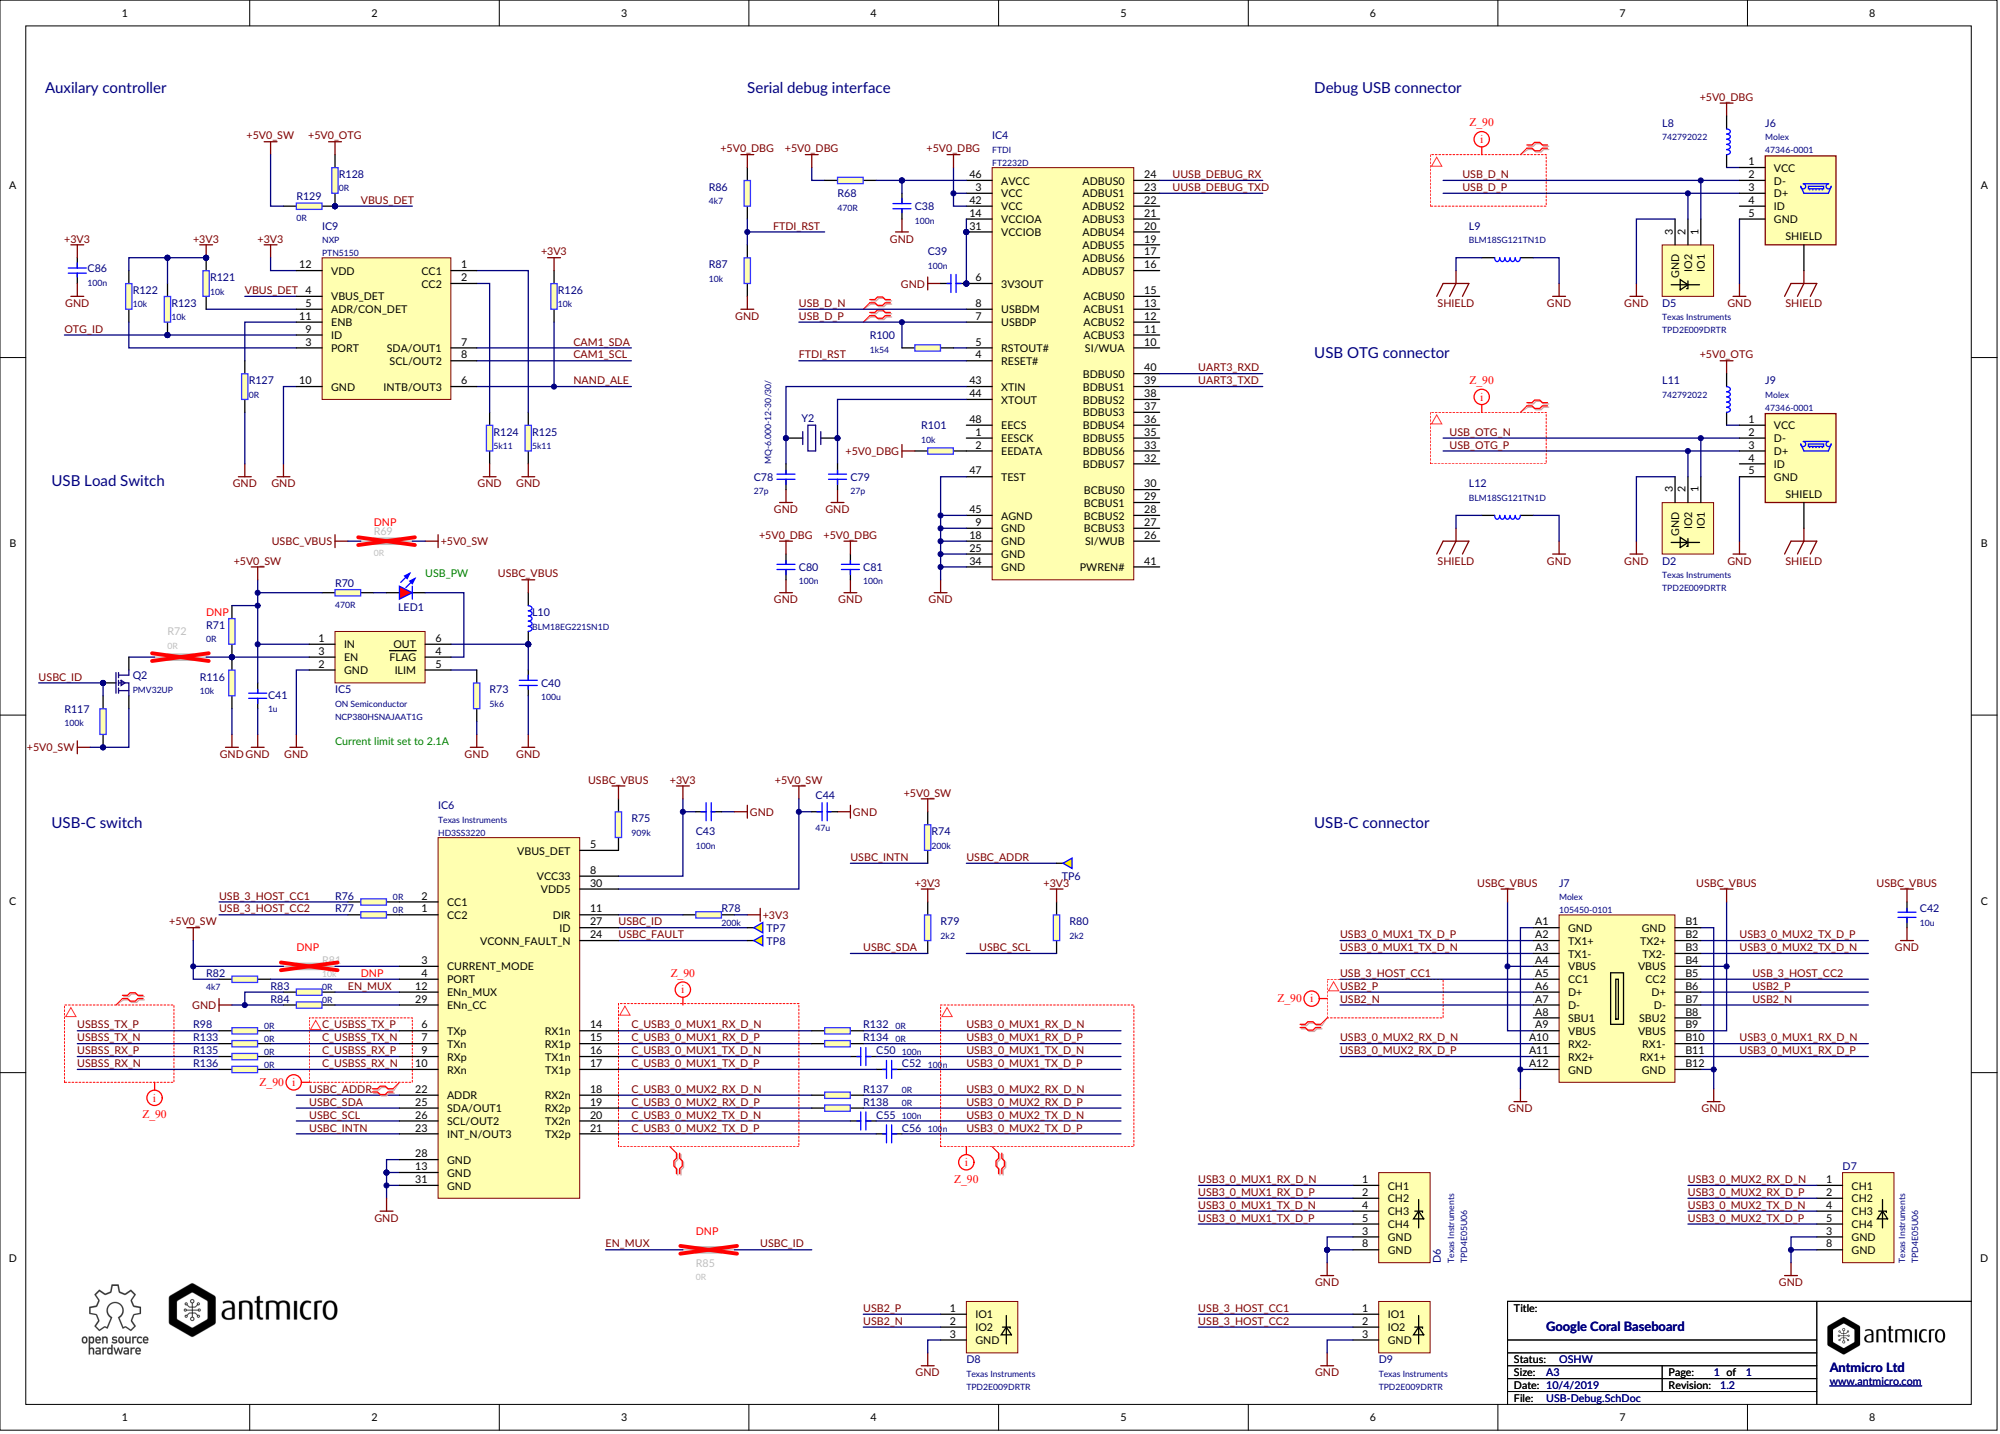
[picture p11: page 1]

PORT 3

XTOUT 44

AGND 45
GND 9
GND 18
GND 25

Current limit set to 2.1A

Size: A3 | Page: 1 of 1
Date: 10/4/2019 | Revision: 1.2

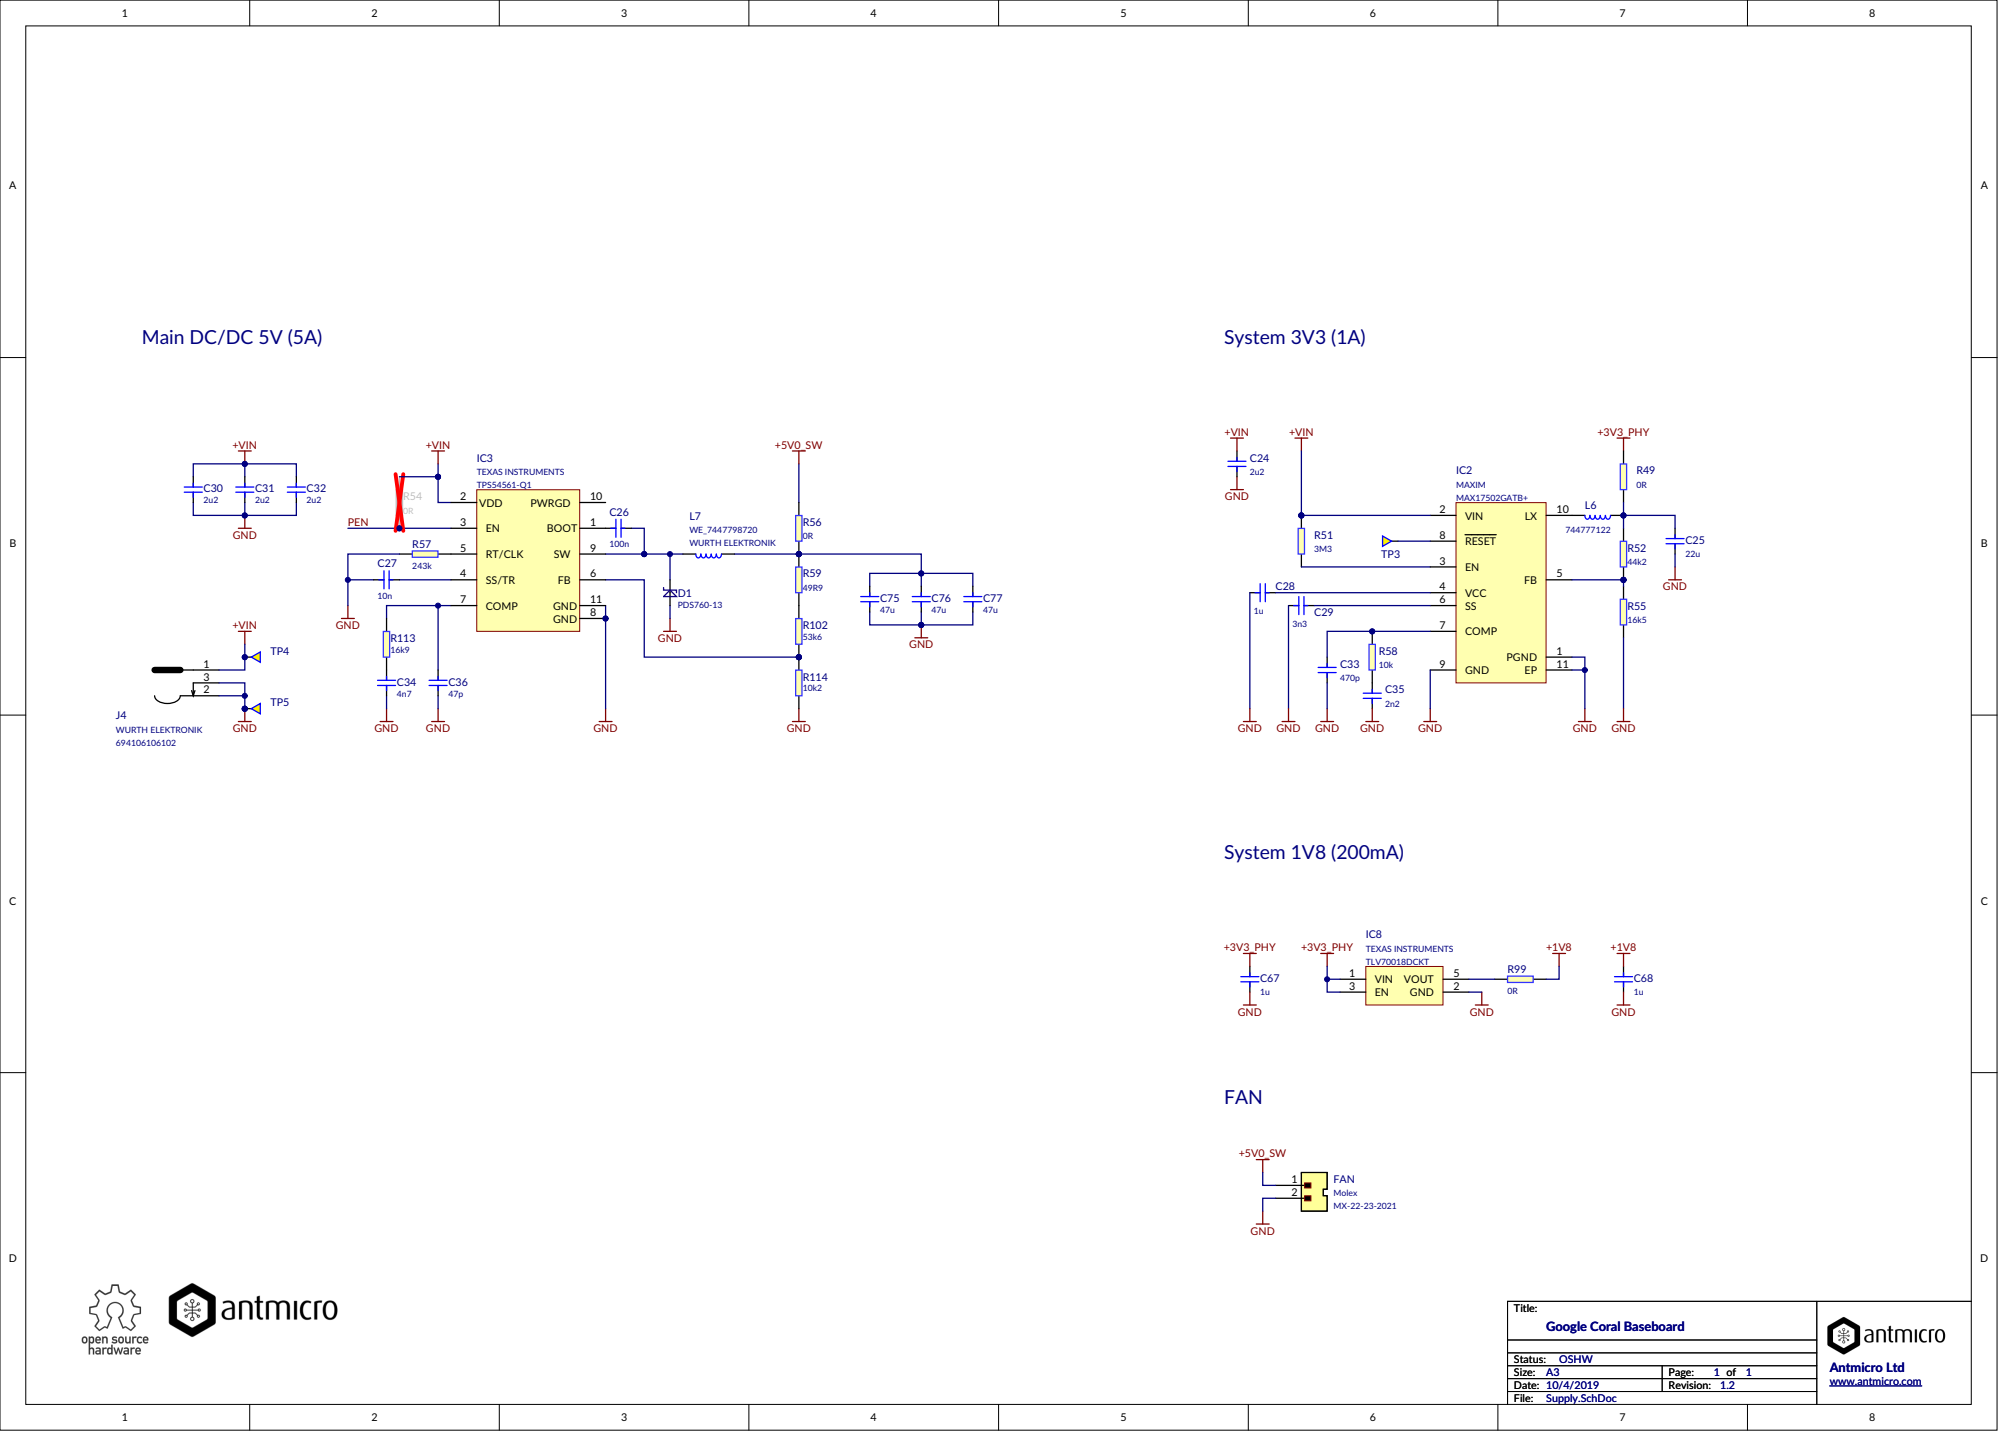
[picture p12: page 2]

COMP 7

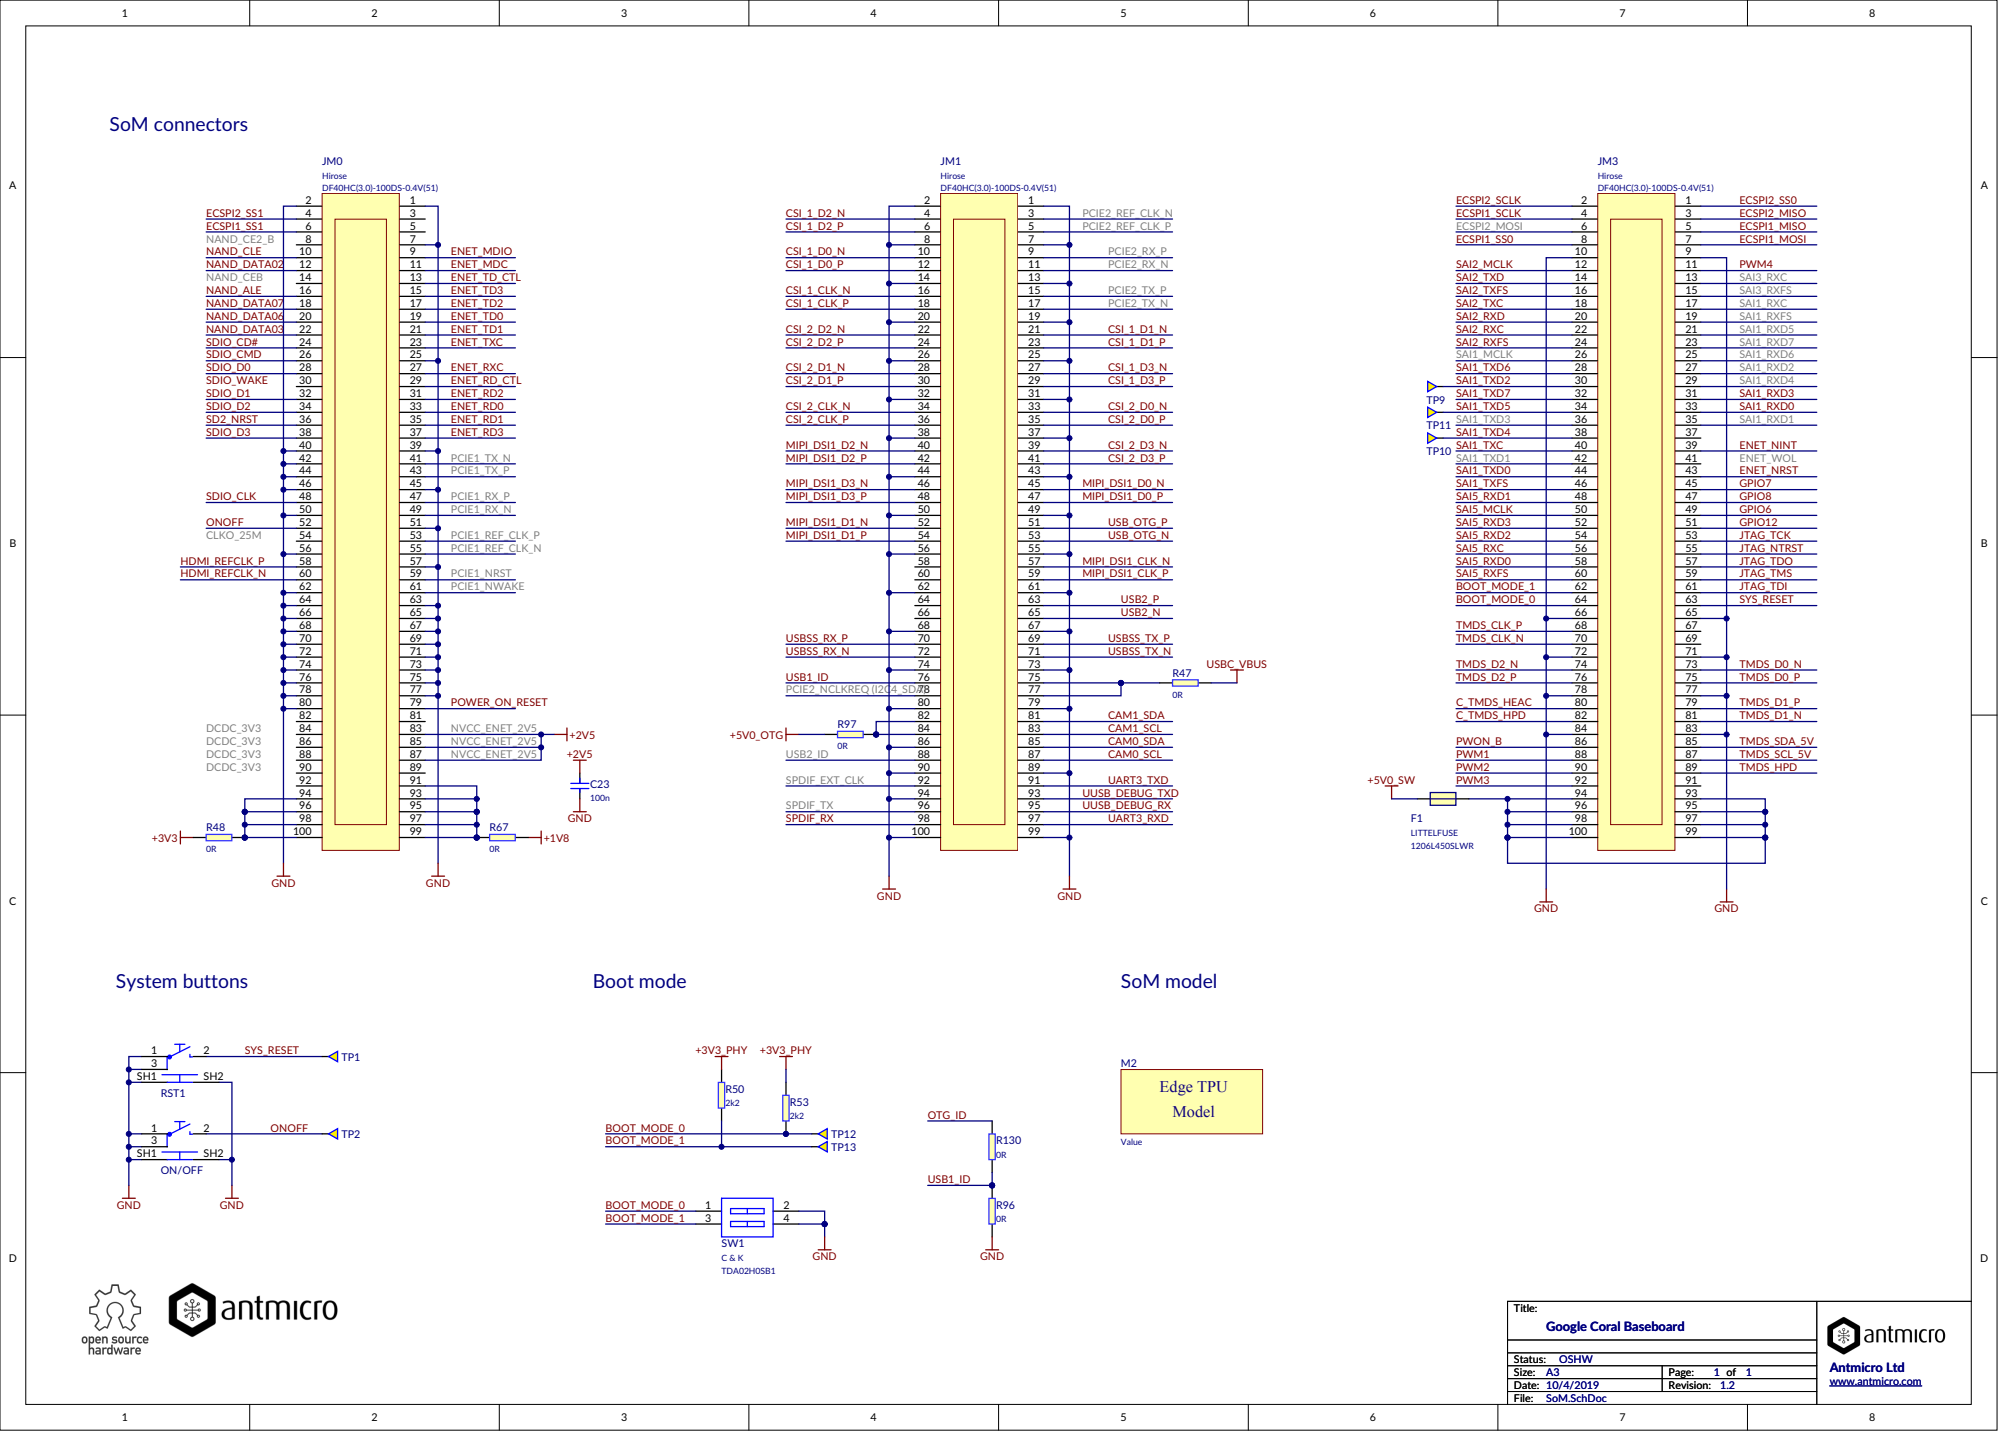
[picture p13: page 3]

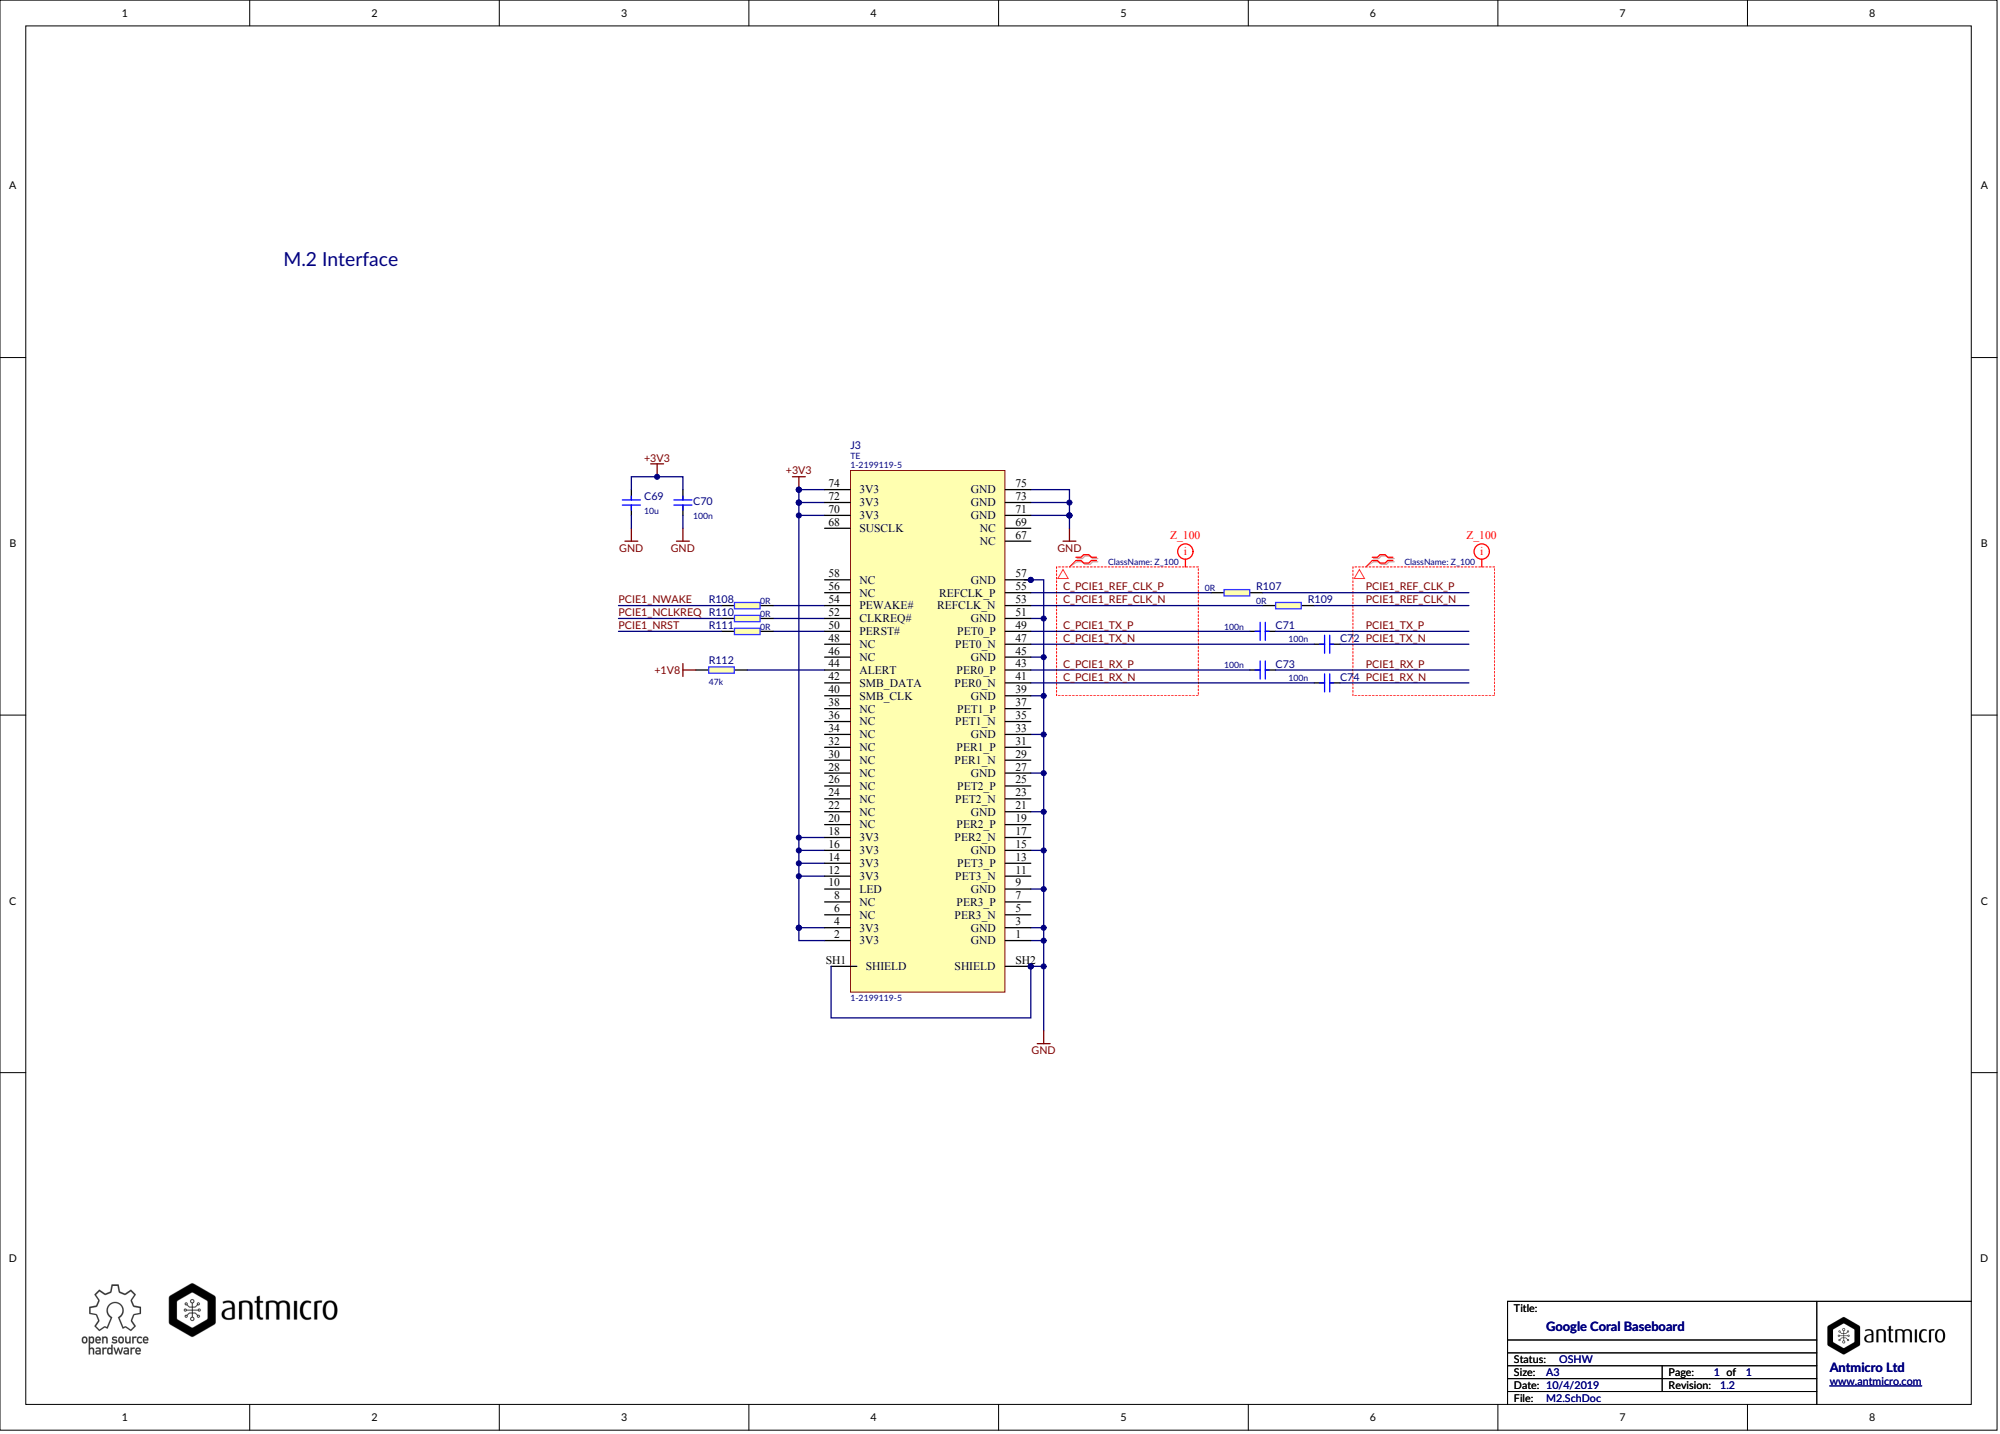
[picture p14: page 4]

PEWAKE# 54 | | | C_PCIE1_REF_CLK_N
CLKREQ# 52 | | | C_PCIE1_TX_P
PERST# 50
NC 48 | | | C_PCIE1_TX_N
NC 46 | | | C_PCIE1_RX_P

SMB_DATA 42 | | | C_PCIE1_RX_N


TMDS Data1+ 5 TMDS Data1- 6 TMDS Data0 Shield 7

TMDS Data0+ 8 TMDS Data0- 9 TMDS Clock Shield 10

DDC / CEC Ground / HEAC Shield 13
CEC 14
SCL 15

+5V Power 18
Hot Plug Detect / HEAC- 19


C_ENET_TD0

C_ENET_TD1 | TXD3 15 TXD2 16 TXD1 17 TXD0 18

C_ENET_RXC | | RXC/PHYAD1 27
C_ENET_RD0


MIPI CSI-2 Camera Interface

LEFT CAMERA RIGHT CAMERA

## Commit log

2019-04-12 Added README
    [M2.SchDoc]
2019-04-17 Updated assembly variant Added BOM
    [CSI.SchDoc, Ethernet.SchDoc, Interfaces.SchDoc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]
2019-10-01 Update project revision, add documentation script
    [google-coral-baseboard.PrjPcb]
2019-10-01 Update distribution of power supplies
    [Interfaces.SchDoc, M2.SchDoc, SoM.SchDoc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]
2019-10-01 Remove documentation
    [google-coral-baseboard-bom.csv]
2019-10-01 Update assembly variant
    [google-coral-baseboard.PrjPcb]
2019-10-01 Update documentation
    [Google_Coral_Baseboard-Rev.1.2-bom.csv]
2019-10-04 Update USB debug circuitry
    [USB-Debug.SchDoc]
2019-10-04 Updated USB host circuitry
2019-10-04 Update PCB components to unify Flipped-On-Layer attribute
    [SoM.SchDoc]
2019-10-04 Update schematic templates
    [CSI.SchDoc, Ethernet.SchDoc, Interfaces.SchDoc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]
2019-10-04 Update assembly variant for R49
2019-10-04 Update PCB documentation
    [Google_Coral_Baseboard-Rev.1.2-bom.csv]
2019-10-29 Update Molex 47346-0001 footprint
    [google-coral-baseboard.PrjPcb]
2019-10-29 Add mounting holes for Coral
2019-10-29 Add JST FAN connector
    [Supply.SchDoc]
2019-10-29 Add antenna clearance
2019-10-29 Revision bumped to 1.3
    [Interfaces.SchDoc]
2019-10-29 HDMI reference CLK moved closer to SoM
    [Interfaces.SchDoc]
2019-10-29 Update schematics
